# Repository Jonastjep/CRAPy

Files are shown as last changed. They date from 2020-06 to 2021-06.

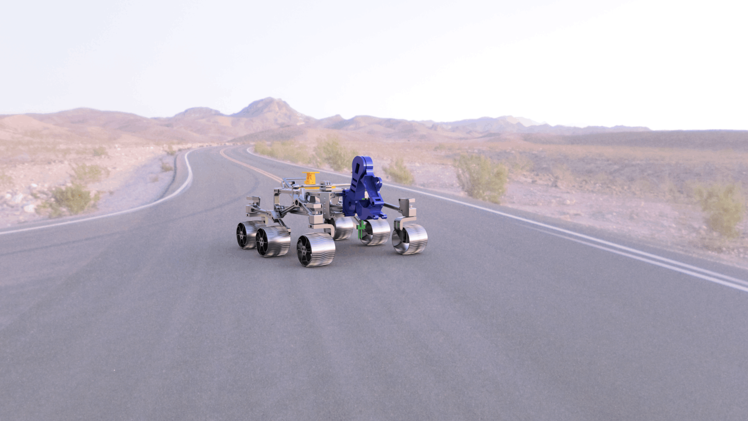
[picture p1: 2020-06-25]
docs/assets/images/for-rendering-final-rover-assembly-2020-jun-22-03-43-39pm-000-customizedview18094494349-png-2000x1126.png

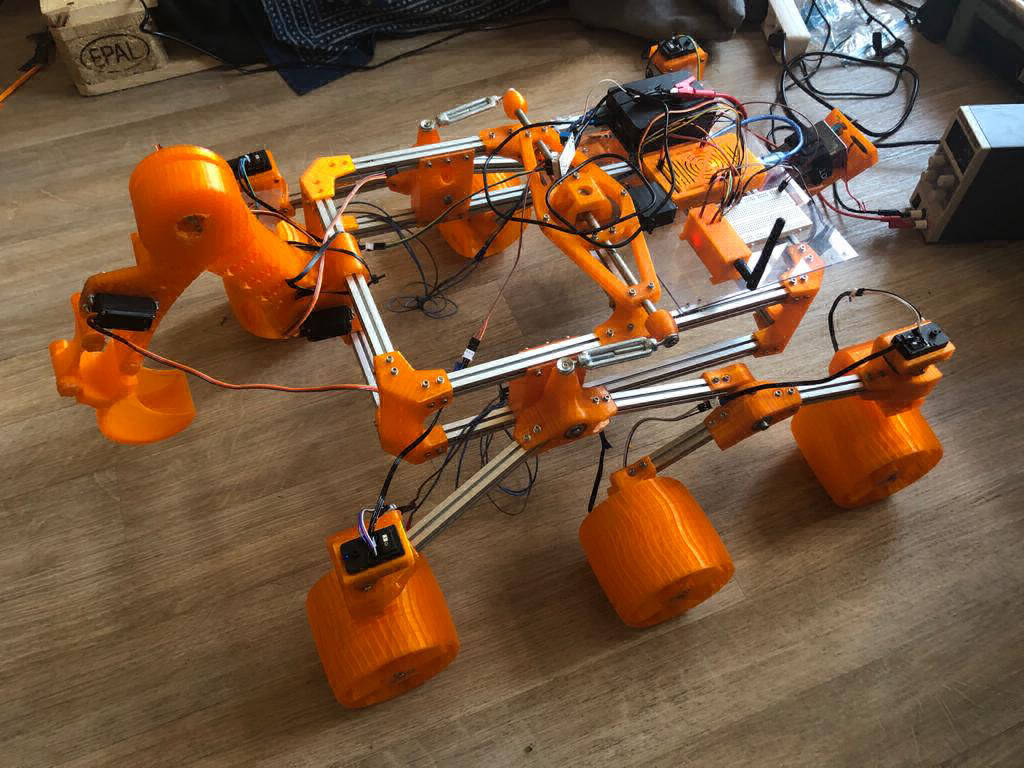
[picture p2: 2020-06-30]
docs/assets/images/whatsapp-image-2020-06-28-at-19.33.52-1024x768.jpg

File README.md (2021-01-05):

# CRAPy Project

The **Controlable Rover Automation Project (CRAPy)** is project is built on the Swappy rover and tries to add new functionalities to it.

# Project Daily Progress Report

## Table of Content

[**Daily Report - 04/01/2021 : Monday 04 January, 2021**](https://github.com/Jonastjep/CRAPy/blob/master/ProgressReport_CRAPy.md#progress-monday-04-january-2021)

[**Daily Report - 05/01/2021 : Tuesday 05 January, 2021**](https://github.com/Jonastjep/CRAPy/blob/master/ProgressReport_CRAPy.md#progress-tuesday-05-january-2021)

[**Daily Report - 06/01/2021 : Wednesday 06 January, 2021**](https://github.com/Jonastjep/CRAPy/blob/master/ProgressReport_CRAPy.md#progress-wednesday-06-january-2021)

[**Daily Report - 07/01/2021 : Thursday 07 January, 2021**](https://github.com/Jonastjep/CRAPy/blob/master/ProgressReport_CRAPy.md#progress-thursday-07-january-2021)

[**Daily Report - 08/01/2021 : Friday 08 January, 2021**](https://github.com/Jonastjep/CRAPy/blob/master/ProgressReport_CRAPy.md#progress-friday-08-january-2021)

[**Daily Report - 09/01/2021 : Saturday 09 January, 2021**](https://github.com/Jonastjep/CRAPy/blob/master/ProgressReport_CRAPy.md#progress-saturday-09-january-2021)

[**Daily Report - 10/01/2021 : Sunday 10 January, 2021**](https://github.com/Jonastjep/CRAPy/blob/master/ProgressReport_CRAPy.md#progress-sunday-10-january-2021)

[**Daily Report - 11/01/2021 : Monday 11 January, 2021**](https://github.com/Jonastjep/CRAPy/blob/master/ProgressReport_CRAPy.md#progress-monday-11-january-2021)

[**Daily Report - 12/01/2021 : Tuesday 12 January, 2021**](https://github.com/Jonastjep/CRAPy/blob/master/ProgressReport_CRAPy.md#progress-tuesday-12-january-2021)

[**Daily Report - 13/01/2021 : Wednesday 13 January, 2021**](https://github.com/Jonastjep/CRAPy/blob/master/ProgressReport_CRAPy.md#progress-wednesday-13-january-2021)

[**Daily Report - 14/01/2021 : Thursday 14 January, 2021**](https://github.com/Jonastjep/CRAPy/blob/master/ProgressReport_CRAPy.md#progress-thursday-14-january-2021)

[**Daily Report - 15/01/2021 : Friday 15 January, 2021**](https://github.com/Jonastjep/CRAPy/blob/master/ProgressReport_CRAPy.md#progress-friday-15-january-2021)

[**Daily Report - 16/01/2021 : Saturday 16 January, 2021**](https://github.com/Jonastjep/CRAPy/blob/master/ProgressReport_CRAPy.md#progress-saturday-16-january-2021)

[**Daily Report - 17/01/2021 : Sunday 17 January, 2021**](https://github.com/Jonastjep/CRAPy/blob/master/ProgressReport_CRAPy.md#progress-sunday-17-january-2021)

[**Daily Report - 18/01/2021 : Monday 18 January, 2021**](https://github.com/Jonastjep/CRAPy/blob/master/ProgressReport_CRAPy.md#progress-monday-18-january-2021)

[**Daily Report - 19/01/2021 : Tuesday 19 January, 2021**](https://github.com/Jonastjep/CRAPy/blob/master/ProgressReport_CRAPy.md#progress-tuesday-19-january-2021)

[**Daily Report - 20/01/2021 : Wednesday 20 January, 2021**](https://github.com/Jonastjep/CRAPy/blob/master/ProgressReport_CRAPy.md#progress-wednesday-20-january-2021)

[**Daily Report - 21/01/2021 : Thursday 21 January, 2021**](https://github.com/Jonastjep/CRAPy/blob/master/ProgressReport_CRAPy.md#progress-thursday-21-january-2021)

[**Daily Report - 22/01/2021 : Friday 22 January, 2021**](https://github.com/Jonastjep/CRAPy/blob/master/ProgressReport_CRAPy.md#progress-friday-22-january-2021)

[**Daily Report - 23/01/2021 : Saturday 23 January, 2021**](https://github.com/Jonastjep/CRAPy/blob/master/ProgressReport_CRAPy.md#progress-saturday-23-january-2021)

[**Daily Report - 24/01/2021 : Sunday 24 January, 2021**](https://github.com/Jonastjep/CRAPy/blob/master/ProgressReport_CRAPy.md#progress-sunday-24-january-2021)

[**Daily Report - 25/01/2021 : Monday 25 January, 2021**](https://github.com/Jonastjep/CRAPy/blob/master/ProgressReport_CRAPy.md#progress-monday-25-january-2021)

[**Daily Report - 26/01/2021 : Tuesday 26 January, 2021**](https://github.com/Jonastjep/CRAPy/blob/master/ProgressReport_CRAPy.md#progress-tuesday-26-january-2021)

[**Daily Report - 27/01/2021 : Wednesday 27 January, 2021**](https://github.com/Jonastjep/CRAPy/blob/master/ProgressReport_CRAPy.md#progress-wednesday-27-january-2021)

[**Daily Report - 28/01/2021 : Thursday 28 January, 2021**](https://github.com/Jonastjep/CRAPy/blob/master/ProgressReport_CRAPy.md#progress-thursday-28-january-2021)

[**Daily Report - 29/01/2021 : Friday 29 January, 2021**](https://github.com/Jonastjep/CRAPy/blob/master/ProgressReport_CRAPy.md#progress-friday-29-january-2021)

[**Daily Report - 30/01/2021 : Saturday 30 January, 2021**](https://github.com/Jonastjep/CRAPy/blob/master/ProgressReport_CRAPy.md#progress-saturday-30-january-2021)

[**Daily Report - 31/01/2021 : Sunday 31 January, 2021**](https://github.com/Jonastjep/CRAPy/blob/master/ProgressReport_CRAPy.md#progress-sunday-31-january-2021)

[**Daily Report - 01/02/2021 : Monday 01 February, 2021**](https://github.com/Jonastjep/CRAPy/blob/master/ProgressReport_CRAPy.md#progress-monday-01-february-2021)

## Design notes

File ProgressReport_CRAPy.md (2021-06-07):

# Progress report of the CRAPy project

## Progress: Monday 04 January, 2021

#### Adjaye:

- Downloaded Fusion 360 and began brainstorming ideas for CAD design.

#### Francesco:
- Carried out first tutorials for processing so I can get some knowledge on the graphical part of the Genetic NN code
- Dowloaded Anaconda, Processing and Atom to work with python
- Read part of the script for creating the plaentary climate model. I have figured out the variables needed but my knowledge of python and physics isn't good enough yet to make sense of most part of the code. If you want to check it out you can find it on (https://github.com/Planet-Factory/claude/blob/master/CLAuDE%20NOM.pdf)

#### Jonas:
- Restructured the github repo for the new project (deleted unecessary files and changed directory struct) and created a [script](https://github.com/Jonastjep/CRAPy/blob/master/Tutorials/createProjStruc.py) to make this file. Also created a table of content for facilitating navigation for the readers.
- Improved the [Genetic NN code](https://github.com/Jonastjep/TinyProjects/tree/main/ObstacleAvoidance/ObstacleAvoidance_js/AI_version "Some cool stuff!") for automated obstacle avoidance ([click here to see the training in action](https://jonastjep.github.io/TinyProjects/)):
	- Changed the NN creation and setup code from homebuilt to TensorFlow.js (more ressource hungry but more efficient on many levels)
	- Tried to improve the fitness function a little (failure to notice any differences, need to rethink the architecture and verify any mistakes)
	- Added a slider change the speed of evolution of the algorithm. Allows for faster training as until now was difficult to see improvement because the training was so slow. We can now focus on the architecture of AI, optimizing the fitness function and seeing how efficient the mutation is (maybe switch from fully random to a Gaussian change). Also until now cross-over has not been implemented, so this should be a big priority.
- Debugged the [user game version](https://github.com/Jonastjep/TinyProjects/tree/main/ObstacleAvoidance/ObstacleAvoidance_js/Game_version) of the AI framework and changed the color palette.
- Looked a little around to see the capabilities of the thermal IR sensor and bicubic interpolation of 2D grid.

#### Juliette:
- Downloaded programs (Fusion 360, installed Python and Atom)
- Read through python textbook, created list of basic commands

#### Marco:
- started to create the environment in which the lidar software can be tested
- learnt how different pathfinding algorithms work in respect to lidar
	- looked over existing code to get an initial idea of how the software can be structured

#### Timon:
- Brainstorm ideas for arm redesign (different platform position, gearing and toolchanger)

#### Sushant:

## Progress: Tuesday 05 January, 2021

#### Adjaye:

- Listened in to the tutorial by Jonas and began testing/practicing making objects in Fusion 360.

#### Francesco:
- Learned the basic use of Arduino and RaspberryPi and how these can be connected to various sensors through flask. The level was very basic but I understood how the basic electronics and programming principles behind switching on and off a LED light connected to an Arduino through a potentiometer. Pretty useful tutorial to get a hang of how arduino's work in case you don't know it yet (https://www.youtube.com/watch?v=nL34zDTPkcs&ab_channel=Afrotechmods)
- Watched another series of tutorials on how to use Processing and how to programme interactive geometrical shapes and drawings
- Attended the amazing tutorial by jonas on how to work with Flask and GitHub
- Dowloaded Git and watched a couple of extra tutorials on how to use Git and the basic principles of Flask

#### Jonas:
- Gave a (very) long and hopefully interesting tutorial about the pleasures of SSH, VNC, Flask and Git/Github.
- Discussed with Sushant the ways he could implement a sensor graphic onto the Flask server and the advantages of JSON or SQLite. Not yet conclusive, so keep an eye on Sushants work.
- Struggled with the AMG8833 thermal sensing module. Got values out, so this is nice, but absolutely impossible to find a way to plot it and refused to use PyGame, which would have no feasible way of implementing to a flask app. Tried matplotlib, seaborn, plotly and openCV, best result to have come out was OpenCV but was not successful at animating it. Just realized that p5.js might be a good possibility, but have to see how to pass the data to the script... Positive side is that the sensor is working and it is possible to see from the values the wiggle of fingers.
	- The problems encountered is how do I create the 8x8 images, and simultaneously send them to the js script for reading
	- **Late night update, possibility using websocket. To be investigated further...**
- Also Started working on a cheat file for the Git/ssh commands. Will be available tomorrow probably

#### Juliette:
- Attended Jonas' tutorials on Git/GitHub, SSH, and Flask and began practicing/researching basic concepts.
- Downloaded and Installed Git and Flask
- Started practicing and brainstorming on Fusion 360 

#### Marco:
- succesfully created version one of the environment to test the lidar. Point clouds are now generated on command if objects are within range of the simulated lidar. Still need to fix so the lidar range is blocked by objects (currently there is clipping).
	- The simulated rover only moves up/down/left/right instead of forward/backwards/rotation -> this needs to be fixed to better simulate the rovers movements
	- the lidar also will need to be changed to simulate blockages

#### Timon:
- Optimize slicer profile for PETG filament and do test prints
- Develop more concrete ideas for the robotic arm and find out what the different available motors are capable of.

#### Sushant:

## Progress: Wednesday 06 January, 2021

#### Adjaye:

- Collaborating with Timon to decide which aspects of the design we will be in charge of and getting the basic run down of the parts needed in this iteration of the project and their importance from Marco and Jonas.

#### Francesco:
- Manged to set my git (baby steps for a bio students)
- Looking into using python to code  for the sensors' module. Still far away from what I need to know

#### Jonas:
- Wrote the Git/Github [tutorial](https://github.com/Jonastjep/CRAPy/blob/master/Tutorials/Setting_Git%26Github.md) for the team
- Managed to stream the thermal camera using Python websockets and processing!! :) This should be very low computing for the RPi and low latency as it's the host computer that does all the work. Nice video example. Still need to do the interpolation (we hope for bicubic) that might make it a bit heavier for the Rpi but not much. But this took some time...
- Had a look at the LiDAR and despaired on the discovery that it can only be controlled through ROS

#### Juliette:
- Began Flask tutorial from the official website
- Created first app with Flask that displays "Hello, world" when using the link of the ip adress.

#### Marco:
- Fixed lidar environment.
	- now only objects in rover fov are added to point cloud - as would be the case with real lidar. movement mechanic logic was changed to make smoother use. rover no longer clips through obstacles. point clouds still generated on command. personal computer broke so started using jonas' spare. files in branch Marco are by marco despite being pushed by different user - this valid until specified. 
- 3d design
	- discussed with adjaye and timon the way forward regarding design of components. outlined 6 reccesary practical aspects of the project; 5x ultrasound mounts for hardpoints onto rover body, robotic arm with manipluation attachment, solar panel/ material deposit tray, fix current defective pieces, camera/lidar mount, other small sensor housings.
	- work split as follows; timon - robotic arm, adjaye - solar panel and material deposit, marco - camera and lidar mount, whole team - fix current defective pieces,  ultrasound mounts and small sensor housings are trivial designs open to whoever wants.

#### Timon:
-3D model bracket that mounts to rover for arm
- discoss with adjaye how the arm and the solar panel can be operated on the rover
- start tallking about ideas of how to stop the axles from slipping

#### Sushant:

## Progress: Thursday 07 January, 2021

#### Adjaye: 
- Continuing to develop ideas for the rover's solar panel and sample box design.

#### Francesco:
- Menaged to connect to raspberry pi from Italy through ssh and VNC, controlled the temperature sensor.
- Next step is try to build a database with sqlite, store in it the data obtained from the temperature sensor and form a graph using Matplotlib. Then display the data using JustGage and then make the graphed data available through a web app made with flask. It's a work in progress
- To do all pf this with my little knowledge I have also been following some tutorials on how to programme with python, especially in the context of 

#### Jonas:
- Discovered the pressure sensor was not working (only after a loooong period of troubleshooting) so had to solder a new one together and conect it to the RPi to allow access through ssh for Francesco. Also had to figure out how to configure the I2P port address for the [Adafruit BMP280 libraries](https://github.com/adafruit/Adafruit_CircuitPython_BMP280/blob/f65303074498e07db883e73c067a8b9e491451a2/adafruit_bmp280.py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). Alot of issues due to the fact our sensor is not genuine. Also had to figure out if it was a BME280 or BMP280 (it's the latter). Alot of time went into just figuring out these things.
- Had a zoom conference with Italy to help with taking control of a remote server (a RPi) and using it to run some python software.
- Spent some time reflashing another RPi and updating it up. Issues with the headless connection through wifi but fixable.

#### Juliette:
- Continued tutorial for a longer app with Flask
- Trip back to Maastricht, delays in both flight and trains.

#### Marco:
- partially installed the neccesary ROS software needed to operate lidar (still proving to be tricky)
- began designing first iteration of the camera/lidar sensor mast
- reviewed current physical design flaws and neccesary improvements 
- reveiwed methods to export point cloud data from ROS into a more managable format for end-used consumption
- set up fusion 360 team and made accessible the previous design of the rover for design reference

#### Timon:
- Develop and 3D print (and improve it again) a snap on attachmet that can be used to attach all other sensors etc. to the rover.
- identify broken parts on the rover that need to be reprinted
- start printing replacement parts with reiforcememnt out of PETG for the rover
- experiment with drilling of the axles to aviod slipping
- retrieving a vice to hold the axles while drilling them
- drilling hoes into all axles to prevent slipping

#### Sushant:

## Progress: Friday 08 January, 2021

#### Adjaye:
- Collaborating with Timon on solar panel and sample box design
- Begin implementing the design into CAD

#### Francesco:
- Still working on the creation of a web app to store and display the data from the temperature and pressure sensor (BMP280). Until now I managed to build a database with sqlite, store in it the data obtained from the temperature sensor. The next step is to form a graph using Matplotlib and display the data using JustGage. Ultimately the app for display will be made with flask but to do so I think I will need to be in maastricht to get some assistance from more experienced prigrammers... Jonas has been very helpful!
- Menaged to create a working database and programme to store the data directly from the sensor. Next step is to create a query, to format the raw data into a readable form. Then a falask web app to visualise this form.

#### Jonas:
- Wrote the Raspberry [Pi setup/connection tutorial](https://github.com/Jonastjep/CRAPy/blob/master/Tutorials/Setting_Up_The_RPi.md) that explains how to setup a headless RPi and take control of it. 
- Also wrote the [ssh and remote control of system tutorial](https://github.com/Jonastjep/CRAPy/blob/master/Tutorials/RemoteConnection_tutorial.md), to explain how to remotely use a GNU/Linux system (specifically RPi) from afar.
- Helped Juliette a little bit with flask (Vorführeffekt) and gave some advice to Francesco.
- Disassembled the suspentions of the Rover with Timon to test out the new PETG part, but infill was too low and piece cracked when pushing it with a bearing. 
- Rethought the fitness function of the genetic AI: add negative fitness points to models that turn too much and that don't push on the forward button. This should take care of the ones that turn in a circle indefinitely as well as the ones that just stop down.
	- Added features that allow for death timer to be removed and added the choice to leave the forward motion to the rover (we can now force the rover to always have it's foot on the accelerator - it totally removes the problem of static cars and disfavours the rotating ones)

#### Juliette:
- Had issues with the Flask app and the virtual environment, solved now.
- Installed PUTTy for SSH and connected to Raspberry pi
- Making app with flask and SQLite for sensors from Raspberrypi

#### Marco:
- continued the design process for the sensor mast, worked through two iterations each using a different design to move camera and optical equiptment. finalised the orientation of equiptment on the mast, as lidar needs a 360 degree unimpeded view whereas if camera and optical equiptment has small blindspots it is not a big issue (given that default position is unimpeded).

#### Timon:
- Develop and test new slicing profile for increased strength PETG parts
- Start printing PETG replacement parts

#### Sushant:

## Progress: Saturday 09 January, 2021

#### Adjaye: 
- Implemented the first version of the sample collection box into Fusion 360 that utilizes a slider crank to open and close the box.

#### Francesco:
No progress due to trip from Italy to Maastrict! The car broke down.

#### Jonas:
- Worked on implementing the new fitness model to the genetic algorithm. The changes don't gives very different results, probably because the values are not well set... Need to sit down and think about the optimal aditions of fitness values to the score.
- Also looked into making the cross-over. I (or someone else from the team) should probably continue the python implementation, as python has many more tools for these tasks. It's just nice that p5.js can be run on the browser.

#### Juliette:
- Database creation using sqlite. Used commands in shell to create a table, insert data, and retrieve the table to ensure proper functioning of code.
- Learn to structure python scripts for database creation as well so commands don't need to be manually entered every time but instead it is better to just call in the python file with the commands included in it.

#### Marco:
- completed the design for the uper part sensor mast where optical sensors are located. now only need to design a secure method to fix bottom end of pvc pipe to rover body and sensor assembly will be complete. **visible in my branch if yous are curious**

#### Timon:
- Continued printing replacement parts

#### Sushant:

## Progress: Sunday 10 January, 2021

#### Adjaye: 

- Day off

#### Francesco:
- Arrived in Maastricht late due to journey delay (broken car)
- Menaged to set up another programme to log data automatically and have been working on a way to let the programme run continously but let it stop at a precise point, like once every single hour it should collect informations, feed them to the database and then stop, to start again in the next hour. Still need to define well how to do it.

#### Jonas:
- total day off :) (almost)

#### Juliette:
- Researched possible sensors that we would be using (still need to know what sensors we have to research how they work)
- Learned about DHT sensors and followed basic tutorials on it

#### Marco:
- nothing this was day off 

#### Timon:
- Continued printing replacement parts 
- Enjoyed the weekend

#### Sushant:

## Progress: Monday 11 January, 2021

#### Adjaye:
- Continuing to work on the sample box v1.

#### Francesco:
- I have been working on the second part in the creation of a web app, trying to form a quary. However, I have been stuck all day on the same problem, the storing table does not get recognised by the gueryTableBMP280.py programme and I can't figure out why!
- Just menaged to make the query work, it was due to a spelling mistake!!!

#### Jonas:
- Printed more wheel parts in PLA and tested using PrusaSlicer instead of Cura: excellent results, I'm converted!
- Reassembled the rover almost fully, the shafts are still a pain to install, but PETG seems promising. Some older parts look on the verge of collapse, but planning on tying to add some epoxy for structural integrity.
- Helped a little bit around with Flask and the ROS installation, when needed.

#### Juliette:
- Went over the GPS files in the github to understand what has been done and how (defining line by line how the python files are written, which also helps to learn python structure, the different functions, and what it is possible to do)
- Attempted to work with pressure/temp sensor to create database using sqlite (not quite successful yet)

#### Marco:
- succesfully downloaded and istalled the neccesary ROS onto a secondary raspberryPi to test if it worked. Did not. had to wipe the microSD and reinstall the software with little success. Now trying to retrace steps and redo all with extra attention to see if steps were overlooked. If the ROS and other software neccesary to run lidar on a raspberryPi can be succesfully downloaded in the following days then there should be no probelem implementing on actual rover. 

#### Timon:
- Made the bracket that attaches the arm to the chassis in fusion 360
- made the motor mount for rotation of the arm in F360
- Transferred bearings from old to new parts and hammered them in
- Assembled suspension and drivetrain related parts of the rover

#### Sushant:

## Progress: Tuesday 12 January, 2021

#### Adjaye: 

- Gathered inspiration for solar panel design
- Prepared for exam on thursday in the evening

#### Francesco:

#### Jonas:
- Started the prints for the camera and LiDAR attachement module, will probably have the module tomorrow
- Managed to finally make the LiDAR work with Marco, what a pleasure to see the point cloud delimiting my room! I just helped debugging a little the commands needed for the setting up
- Discussed sensor modules with Francesco and Juliette. Starting to figure out where we want to go, probably starting on the datacollection tomorrow or something. We'll see how well the nRF24 sensors work and how we can implement all this.
- Managed to create a mapping inteface for GPS data. Works super nicely, just waiting to have implemented many more features than simply all data or query a certain amount of latest data (for example, give two dates, and map the travel between; also centralize the map on the tracks first point, still to do). Will probably make pull request tomorrow. Had issues with cached json files in browser, but found solution.
- Wrote some demos for data conversion between CSV, SQLite database and JSON. Good for the people of the group interested.
-Also this mapping is proof of concept of how we will make all of the interactive plots etc on the webapp: This worked fabulously and leaves us with alot of control. Need to discuss this with the others tomorrow.

#### Juliette:
- Discussed sensors with Jonas and Francesco to figure out a plan (how to implement them together)
- Attempted with Francesco to establish communication between Arduino and Raspberry pi through rnf24l01 transceivers (searched for standard connection mappings between sensors and raspberry pi) - Had issues making this work.
- Found a tutorial for nrf24l01 communication from Arduino to Arduino (instead of Arduino to Raspberrypi) https://lastminuteengineers.com/nrf24l01-arduino-wireless-communication/ (will run this on wednesday with Francesco)

#### Marco:
- lidar now working (mainly thanks to jonas for troubleshooting with me). required several reflashing of sd card until we chose to use a disk image with ROS kinetic alreadz installed with ubuntu 16. this allowed us to bypass several installation steps that were previously problematic. running codes to activate and perate lidar are as follows. `roslaunch ydlidar_ros_driver X4.launch` hen in another windown run `rviz` to open the ROS software. then within the ROS software `file>open confi>ubuntu>ydlidar_ws>src>ydlidar_ros_driver/launch/lidar.rviz` to get real time lidar info on screen. 
	- looks cool and proves it works, does not yet actually create a map to then be stored. The next steps are as follows; implement SLAM to create a static point cloud that can then be exported to flask web app.this will alow the end user to view the map created by the rover in real time (hopefully). 
	- should it all work then the actual rasPi used on the rover will need to be reflashed with disk image used on test rasPi. everything will need to be redone on the actual rasPi, for this first i will make a tutorial/log of everything we did to get the current rasPi working, not only to make replication easier but also to ensure future groups are able to use the LiDAR module if they want to.

#### Timon:
- Discussed with Adjaye various ways of how the solar panel could be lifted (worm gear, regular gear reduction, linear actuator)
- discussed more concretely what areas of the front of the rover are available for which mechanisms
- Designed the base of the arm which holds the first link 
- Started with the first link of the arm.

#### Sushant:

## Progress: Wednesday 13 January, 2021

#### Adjaye: 

- Took the day off as the exam was the next day.

#### Francesco:
- Have been working on the connection between raspberry pi and arduino using the radio frequencies. Following this tutorial https://medium.com/@anujdev11/communication-between-arduino-and-raspberry-pi-using-nrf24l01-818687f7f363
- The tutorial we were following didn't prove useful so we changed plan, with Juliette we will try to connect two arduinos, one attached to the rover's raspberry pi and one attached to the headquarters' raspberry pi.
- With jonas and juliette we menaged to make two NRF24L01 communicate, one reciver and one transmitter, but we fail to have a clear connection where we have a message being recieved aaandaa a message being sent back, to confirm the message being recieved.

#### Jonas:

#### Juliette:
- Worked with Francesco on nrf24l01 communication. Attempted again to follow a tutorial between Raspberry pi and Arduino (see Francesco's report for link) but it was unsuccesful. Decided to stick with Arduino to Arduino wireless communication.
- With the help of Jonas, Francesco and I finally made the two nrf24l01 communicate, following a simple code for two-way transmission (one code for the transmitter and one for the receiver) https://forum.arduino.cc/index.php?topic=421081
- Problems receiving an acknowledgement message back from the receiver so transmitter cannot confirm message has been successfully received.

#### Marco:
- wrote tutorial on how to set-up rasPi for lidar operation, starting from a new blank rasPi all the way to lidar operation. Visible under tutorials folder of master branch and titled Lidar_rPi_tutorial.md
- worked on initial  3d printed parts of the sensor mast design to prepare them for assembly.

#### Timon:
- Improved the base of the arm and other parts so that the first link can rotate down as far as possible. This is so that the arm can be as short as possible to make it more lighweight and easier to lift for the motors
- indentified broken hub parts that need to be replaced
- retrieved heat inserts and screws from broken parts
- searched together all screws neccesary for the wheel assembly
- put heat inserts and screws into new parts
- Partially assembled hubs and motors

#### Sushant:

## Progress: Thursday 14 January, 2021

#### Adjaye:

- Day of exam, continued to work on design in the evening.

#### Francesco:
- Found this tutorial https://forum.arduino.cc/index.php?topic=623796.0 to conenct arduinos and send data. We are going to test the code and connection between our two NRF24L01 modules 
- With Juliette we menaged to make two antennas nRF24L01 communicate at long distance, sending messages and receving them. The confirmation of having recieved the message doesn't work from reciver to transmitter. Next step is to make that work, so that we can have the rover confirming a message has been recieved or sent. N.B. This was difficult (jonas agrees)
- We menaged to get the reciver to send a confirmation signal to the transmitter. The problem wasn't the code but rather the connection and the equipment we were using, probaby in relation to the cables and the way in which they connect

#### Jonas:

#### Juliette:
- Working with Francesco, still trying to make the nrf24l01 sensors work.
- Researching how to send data from sensors through transceivers.
- nrf24l01 worked!! at "long" distance! Acknowledgement message still missing, need to review code and find where it fails to send confirmation receipt.
- Managed to get 7 confirmation messages from the receiver! Possible problems with connections
- Placed a few screws here and there in the rover

#### Marco:

#### Timon:
- Realize that a few more hubs are broken
- Harvest heat inserts from old hubs and put into new hubs
- Shorten axles that were too long, using a plastic bag in the process
- mount wheel carriers onto the suspension assembly
- attach all 10 motors, by numbers to each position
- shorten screws because there weren´t enough of the right size
- attach wheels
FINALLY 10 WHEELS THAT DON´T SLIP!!! 

#### Sushant:

## Progress: Friday 15 January, 2021

#### Adjaye:

#### Francesco:
- With Juliette we have been trying to send the data directly from the arduino to the other through he nRF24L01 module underthe form of strings. This tutorial might be useful https://forum.arduino.cc/index.php?topic=436525.0. We should also start to think about the way to send a serial communication from the sensors to the raspberry pi and form a database there. But this is for future moment.
- We gave up on sending data between the two nRF24L01 modules because the connection is too unstable and continously brakes, which also makes it very difficult to test the code and the way in which data are sent. NOTE on future improvements: use more powerful antennas and to try to have a more stable connection

#### Jonas:

#### Juliette:
- Spent first hours working with each sensor (separately) to obtain individual codes as well as proper cable connections for each (that way we can be sure we can make them all work properly. Did this for mq2-gas sensor | hcsro4-ultra sound sensor | dht11 - temperature and humidity sensor)
- Worked on combining code of nrf24l01 transmitter sensor with one of the individual scripts (chose hcsro4 - ultra sound sensor for this because it was the one working best)
- Assembled the arduino connection with the two sensos (nrf24l01-transmitter and hcsro4)
- Ran into problems compiling the script due to type mismatch between the needed type for the transmitter (String) and the one established in the sensor (long)
- Worked with Francesco finding tutorials to send sensor data from one Arduino to the other as Strings
- With the help of jonas we used .concate() to adhere the data into a string, this solved the compiling problem
- Uploaded the script and attempted to send sensor data over the transceivers. The receiver did not get any message at all. Printed values in the code to make sure the data variable was indeed containing the data received from the ultra sound sensor, this was correct. 
- Attempted to run simple code again (which had work the day before and had even sent acknowledgement receipts). This connection failed as well. Thus, the problem was deemed to be within the connection of the trasnceivers. Gave up on sending data between the nrf24l01 modules.
- Focused on producing a combined code by adding one more sensor (the mq2- gas sensor)
- Managed to compile a code containing all the info for the nrf24l01 transmitter, the hcsro4 ultra sound sensor, and the mq2 gas sensor.
- Made all connection to the arduino, uploaded the script, ran it. Successful retrieval of data.

#### Marco:

#### Timon:
- experiment with rubber bands to determine what extensions they should operate at and what force they are able to provide
- Designed first link of the robotic arm

#### Sushant:

## Progress: Saturday 16 January, 2021

#### Adjaye:

#### Francesco:
- Have been working on two main things, the first one is to find a way to transform the data from the arduino into a json format to be sent over to the raspberry pi. The other is the creation of a programme to recive the data on the raspberry pi and serial it into different variables to store in arrays which will then be used to form sqlite database. I have menaged to get a bit further on this part, mainly due to the fact that today I didn't have any access to the arduino, so it was difficult to test the code.
- I still have to understand better how to sort out the data for the serial communication, but once that is done, the next step is create a flask app and display all the data collected into the sqlite database.
#### Jonas:

#### Juliette:
- Looked into JSON structure in arduino to send organized data from the code of the arduino to the Raspberry pi
- Cleaned up a bit the combined code of the arduino

#### Marco:

#### Timon:
- starting with printing of parts of the robotic arm

#### Sushant:

## Progress: Sunday 17 January, 2021

#### Adjaye:

#### Francesco:
- Scratched off part of yesterday's work because json is needed after the data has been stored in sqlite, not before. Menaged to write a code that takes the data from serial of arduino, stores them into a sqlite database.
- Through another programme I convert the sqlite data into the json type data, which will be then used in the flask app that I am currently writing.
- All these programs still need to be tested, but the main part of that will be simply trubleshooting
- We will also need to start to write a programme for the arm and the light sensors.

#### Jonas:

#### Juliette:
- Added dht11 sensor to the combined code in the arduino. (Now this code has nrf24l01, hcsro4, mq2, and dht11 implemented - Compiled successfully).
- Organized data in a variable that separates values with a ",". Need to figure out how to implement json structure. (jonas explained, json not needed from Arduino).
- Error when running as the data for dht11 sensor returns 0 and 0 for temperature and humidity.
- Ran sensor individually with script done on friday, it works. Currently trying to find the issue within the combined code as the logic and commands are the same.

#### Marco:

#### Timon:
- continue printing parts of the robotic arm
- testing fitment of pars
- changing parameters of the parts (e.g. bearing fitment) 

#### Sushant:

## Progress: Monday 18 January, 2021

#### Adjaye:

- Presented  slided crank design to Marco, the design had too many issues in that it had too many moving parts, and was not feasible for the space of the rover and its other components. The design for the solar panel had a similar issue and would have gotten in the way of the lidar and camera.

-Beginning of a new design for both collection box and solar panel.

#### Francesco:
- Created the first part of the web app and tested it with a randomly populated set of data. Passed on the whole day trouble shooting, the code is very big.
- Worked with Chart.js and revisioned how to make graphs

#### Jonas:

#### Juliette:
- Found issue with dht11 sensor, fixed code (was missing a read command before retrieving the data). 
- Now working with bmp280 sensor. Having issues running examples and actually, any code ("sensor not detected").
- Problem solved with the help of Jonas: Edited library, used the SPI protocol instead of I2C, and added .begin() command. 
Now implemented individual script into combined code. 
- All 5 sensors (nrf24l01, hcsro4, mq2, dht11, and bmp280) are now in the script :) Everything runs correctly!
- Organized the data (small details such as no spaces, different headers, proper separators)
- Placed the connections in the Arduino Mega taking into account future needed pins (bmp280 changed to I2C since SPI is needed for nrf24l01).
- Need to add GPS sensor now. Running individual script, I get responses but no data. Might be due to our positioning not getting any data from satellites.
- Soldered cables, added some heat inserts, and used a hammer for apparently the first time!?

#### Marco:

#### Timon:
- designing second link of the robotic arm
- printing more parts of the arm
#### Sushant:

## Progress: Tuesday 19 January, 2021

#### Adjaye:

- Continuing to work on design.

#### Francesco:
- Continued with yesterday's trouble shooting and have been working on some ideas for the video

#### Jonas:

#### Juliette:
- Attempted to make GPS work. Errors in connections -> "Check wiring". It doesnt recognize the module in the program.
- Note: Tx and Rx connections are inverted to arduino!!
- Examples not running properly
- Using GPS code from github returns empty data (but at least sensor is running now). Implemented code into combined script.
Terrible weather might be making the connection to satellites difficult.

#### Marco:

#### Timon:
- take all parts and assemble to a working arm! (longer than expected)
- print more hubs that don´t break (more perimeters jonas!)
#### Sushant:

## Progress: Wednesday 20 January, 2021

#### Adjaye:

- Finished design, the new collection box design recieved the go ahead as well as the solar panel raiser.

#### Francesco:
- Adapted the web app code with the Arduino code from Juliette. I have also created two databases to store data from the GPS in one, and data from the sensor in the other.
- Also began to write the script for the video

#### Jonas:

#### Juliette:
- Starting box design for sensors, taking measurements.
- Need to add more ultrasound sensors to code!

#### Marco:

#### Timon:
- Construct part that pitches and rotates the toolhead
- adapt the grabber
- print grabber
- steal jonas´s measurements and make an alternative model of his desing without consent :P
- start printing pieces to hold solar panel

#### Sushant:

## Progress: Thursday 21 January, 2021

#### Adjaye:
- Solar Panel raiser was dropped due to lack of time and so preparing the collection box was put on priority.

#### Francesco:
- Finished the script for the video this morning. I am waiting for a reply from the members of the team.

#### Jonas:

#### Juliette:
- Finished box design. Need to check measurements are proper, design is feasible and efficient. Then need to print.
- Added 4 ultrasound sensors to the code (quite lengthy, might be optimzed).
- Noticed that the sensors dont detect me standing in front but it does detect a box - or my hand - so.

#### Marco:

#### Timon:
- Assemble grabber as far as possible without motors
- break holder for solar panel
- make new design for solar panel holder
- test motors (they move)
- print new solar panel holders
- print knuckles wrong (not mirrored)
- print rotating thingy

#### Sushant:

## Progress: Friday 22 January, 2021

#### Adjaye:

- Cutting plexiglass for the assembling of the collection box.
- Assembled turning axle box.

#### Francesco:
- Worked on a light following system for the rover
- Wrote part of the report's introduction
- Revised the web app code

#### Jonas:

#### Juliette:

#### Marco:

#### Timon:
- adapt code to have 6 servos
- convert code such that settings are done and displayed in degree
- adapt script 
- be happy

#### Sushant:

## Progress: Saturday 23 January, 2021

#### Adjaye:

- Helped with the making of videos
- Sanding/adjusting the collection box
- As it would turn out the collection box may not be most practical so a different one was designed in Fusion 360

#### Francesco:
- Took half of the presentation videos
- Soldered and assembled the light following system
- Wrote part of the report

#### Jonas:

#### Juliette:

#### Marco:

#### Timon:
- adapt script of what I say. 
- get articles for the report
- work ( the thing where you do something and get money)

#### Sushant:

## Progress: Sunday 24 January, 2021

#### Adjaye:

#### Francesco:

#### Jonas:

#### Juliette:

#### Marco:

#### Timon:
- wire up rover (ORganize cables wth zip ties, solder connections, put connections in the rover NICELY!)
- Red-> grabber, Purple-> rotation base (everything else in between follows the colors of the rainbow shorter wavelength -> further down the arm).
- record my parts of the video
- peer review 
- vibe
- collect key points for the report
- 

#### Sushant:

## Progress: Monday 25 January, 2021

#### Adjaye:

#### Francesco:

#### Jonas:

#### Juliette:

#### Marco:

#### Timon:

#### Sushant:

## Progress: Tuesday 26 January, 2021

#### Adjaye:

#### Francesco:

#### Jonas:

#### Juliette:

#### Marco:

#### Timon:

#### Sushant:

## Progress: Wednesday 27 January, 2021

#### Adjaye:

#### Francesco:

#### Jonas:

#### Juliette:

#### Marco:

#### Timon:

#### Sushant:

## Progress: Thursday 28 January, 2021

#### Adjaye:

#### Francesco:

#### Jonas:

#### Juliette:

#### Marco:

#### Timon:

#### Sushant:

## Progress: Friday 29 January, 2021

#### Adjaye:

#### Francesco:

#### Jonas:

#### Juliette:

#### Marco:

#### Timon:

#### Sushant:

## Progress: Saturday 30 January, 2021

#### Adjaye:

#### Francesco:

#### Jonas:

#### Juliette:

#### Marco:

#### Timon:

#### Sushant:

## Progress: Sunday 31 January, 2021

#### Adjaye:

#### Francesco:

#### Jonas:

#### Juliette:

#### Marco:

#### Timon:

#### Sushant:

## Progress: Monday 01 February, 2021

#### Adjaye:

#### Francesco:

#### Jonas:

#### Juliette:

#### Marco:

#### Timon:
fun

#### Sushant:

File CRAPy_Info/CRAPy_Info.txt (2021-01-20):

pwd  	      : BroverInc
user 	      : pi
computer name : broverpi

static ip_address=192.168.4.1
ssid: BroverInk_Network
pwd: BroverInk1234

Sensor Mast:
GPIO:
17 Tilt - Slim servo
27 Pan - Thick servo

Disable access point :

- sudo systemctl disable hostapd dnsmasq
- comment the static ip config in /etc/dhcpcd.conf
- sudo reboot

Enable access point

- sudo systemctl enable hostapd dnsmasq
- comment the static IP config in /etc/dhcpcd.conf
- sudo reboot

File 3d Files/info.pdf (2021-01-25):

Print every file once, except the pillar.stl which needs four (4) copies.

Components in red are pre-existing, grey is what needs to be printed.

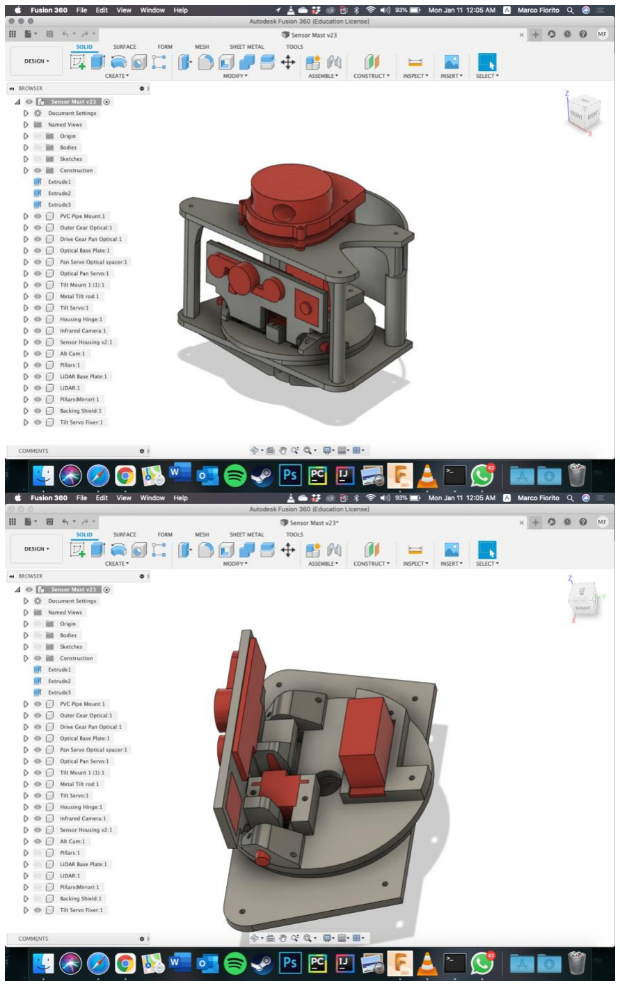
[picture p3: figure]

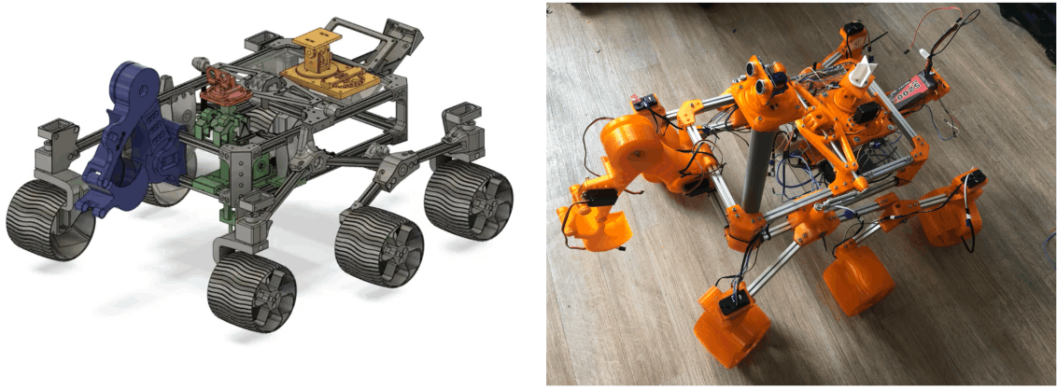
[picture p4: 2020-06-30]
docs/assets/images/screen-shot-2020-06-30-at-12.04.13-pm-1132x418.png

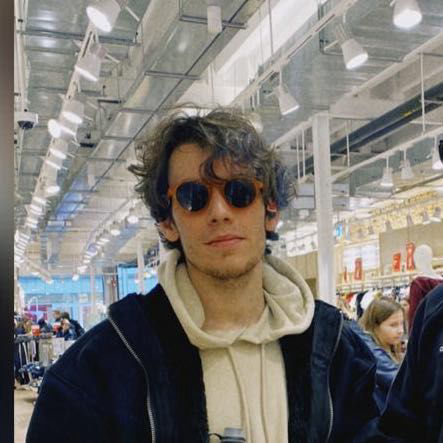
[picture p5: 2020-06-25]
docs/assets/images/69473030-2541841602751203-3235094702887111045-n-443x443.jpg

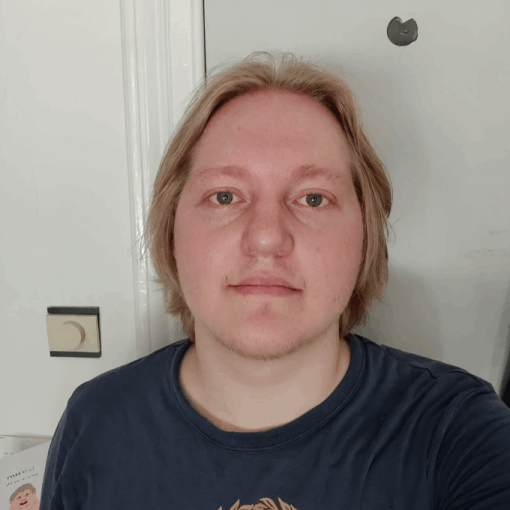
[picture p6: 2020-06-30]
docs/assets/images/screen-shot-2020-06-29-at-1.16.12-pm-510x510.png

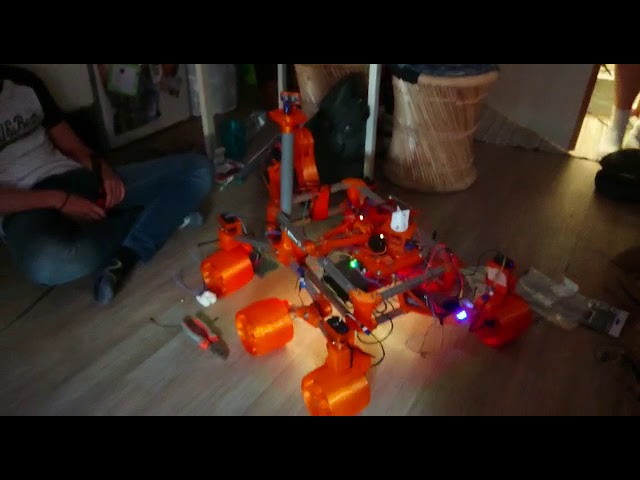
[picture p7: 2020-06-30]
docs/assets/images/mobirise2020529-131212020-5-2-9-54-42.jpg

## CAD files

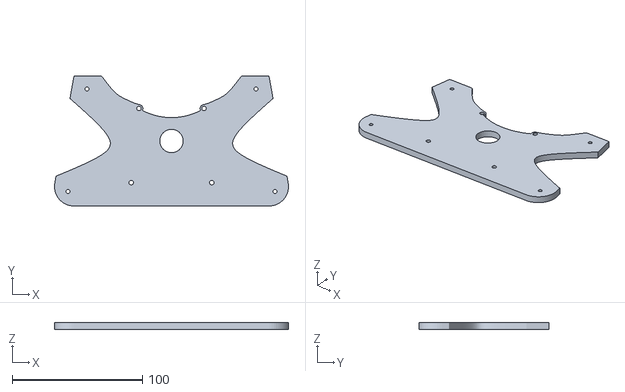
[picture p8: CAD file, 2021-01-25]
3d Files/Sensor Mast v22 indv comp/LiDAR Base Plate.stl
180.0 x 100.0 x 5.00

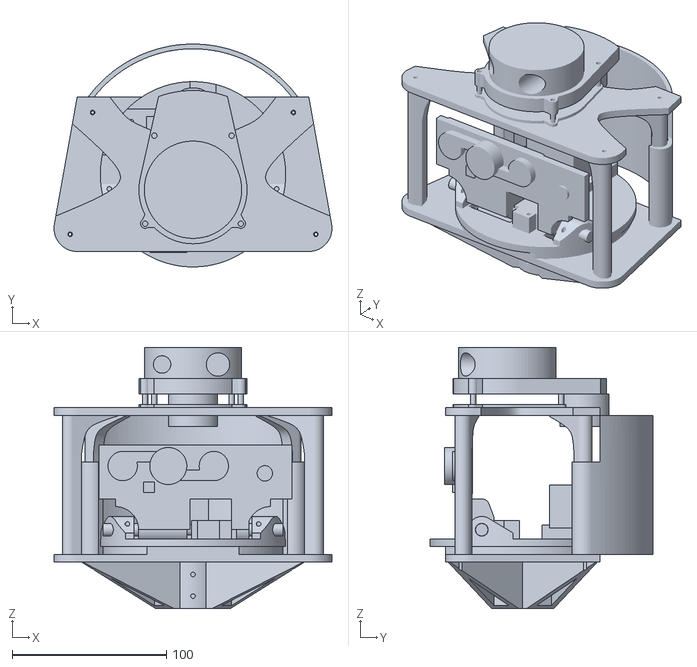
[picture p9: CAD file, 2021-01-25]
3d Files/Sensor Mast v22.stl
180.0 x 144.3 x 169.0

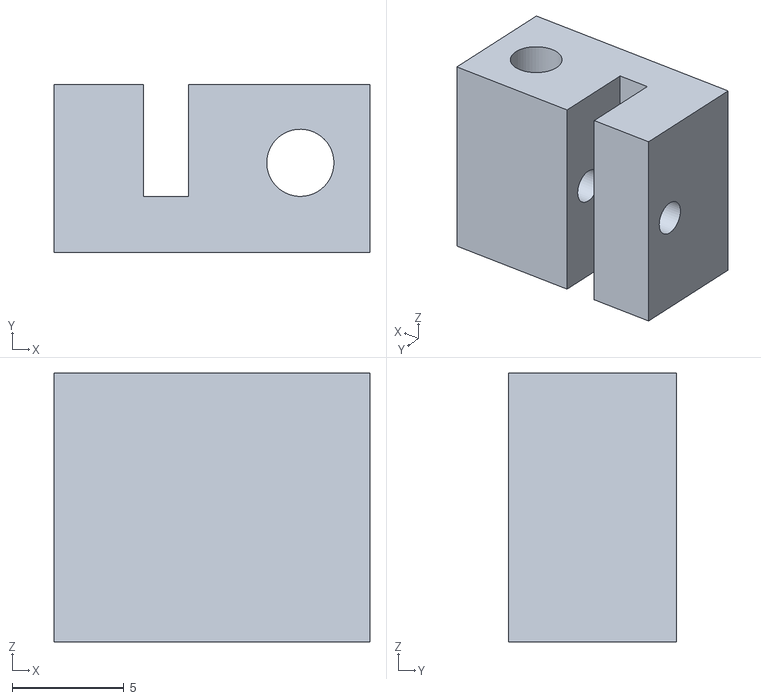
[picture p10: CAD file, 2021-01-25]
3d Files/Sensor Mast v22 indv comp/Tilt Servo FixerBody2.stl
14.1 x 7.49 x 12.0

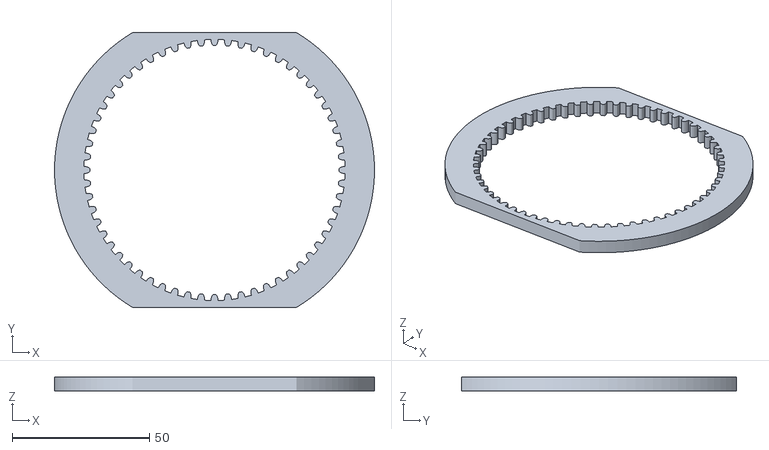
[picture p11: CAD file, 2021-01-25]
3d Files/Sensor Mast v22 indv comp/Outer Gear Optical.stl
116.4 x 100.0 x 5.00

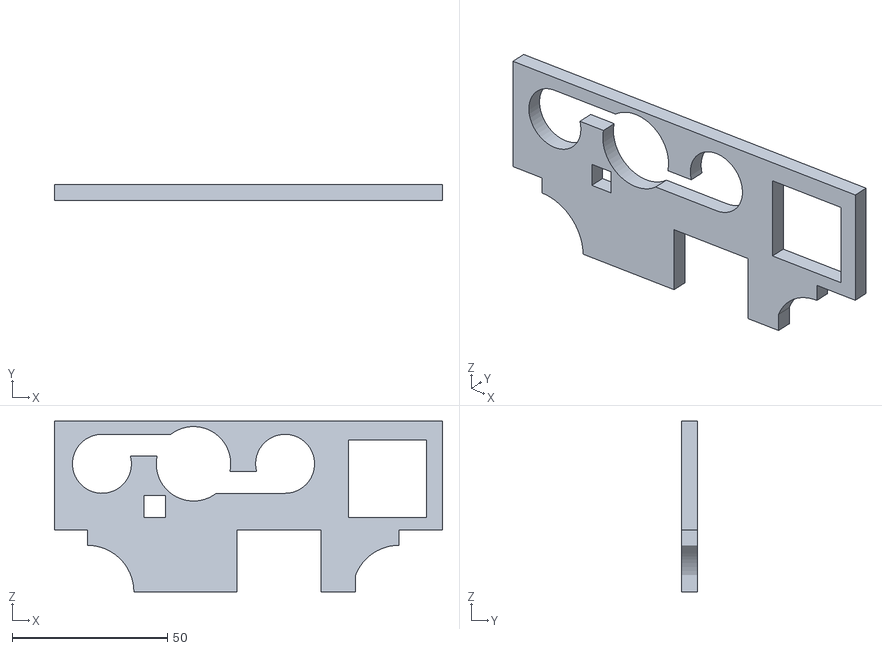
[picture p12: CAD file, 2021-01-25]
3d Files/Sensor Mast v22 indv comp/Sensor Housing.stl
125.0 x 5.00 x 55.0

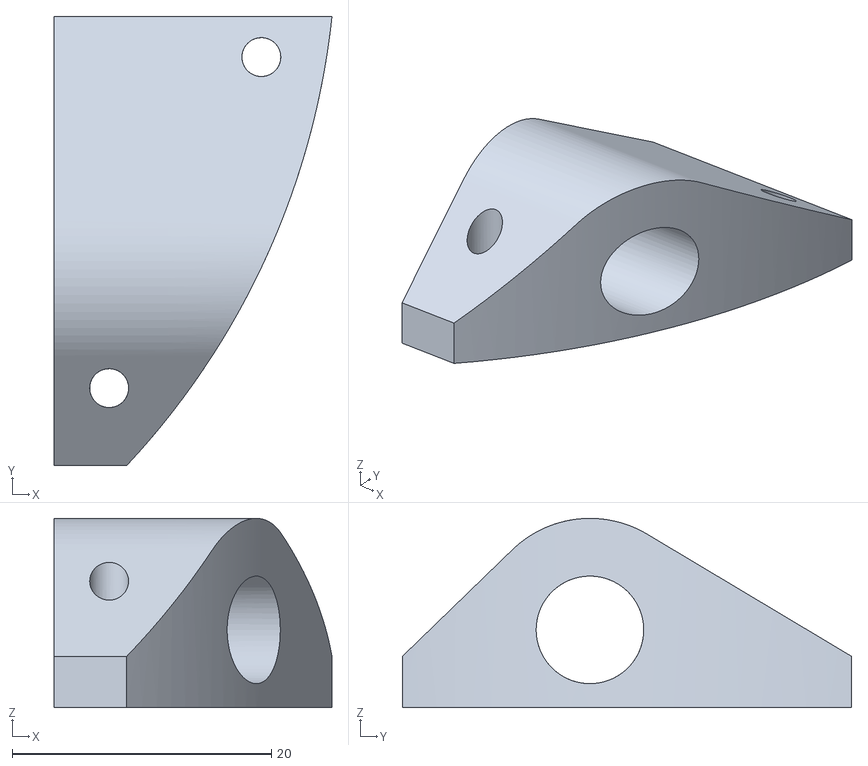
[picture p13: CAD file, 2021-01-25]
3d Files/Sensor Mast v22 indv comp/Tilt Mount Body1.stl
21.4 x 34.7 x 14.6

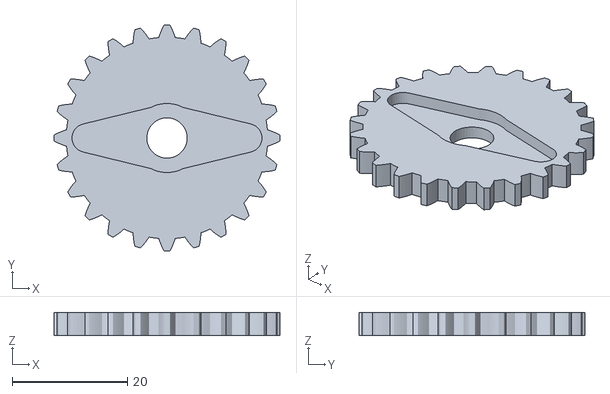
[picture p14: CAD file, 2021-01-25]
3d Files/Sensor Mast v22 indv comp/Drive Gear Pan Optical.stl
39.3 x 39.3 x 4.00

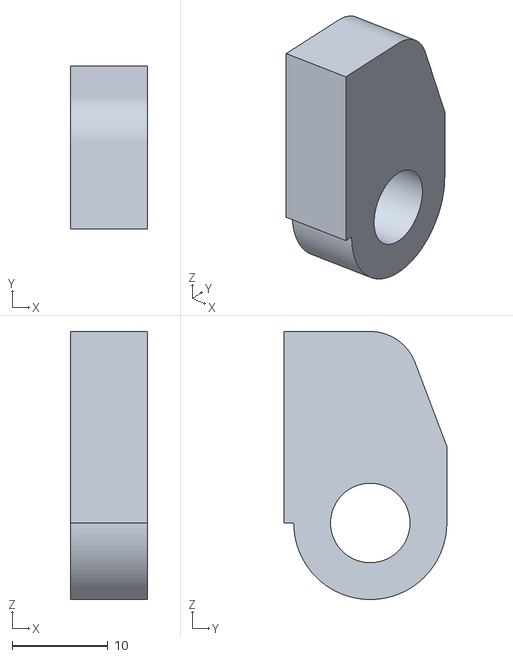
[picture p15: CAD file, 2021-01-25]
3d Files/Sensor Mast v22 indv comp/Hinge Body2.stl
8.00 x 17.0 x 28.0

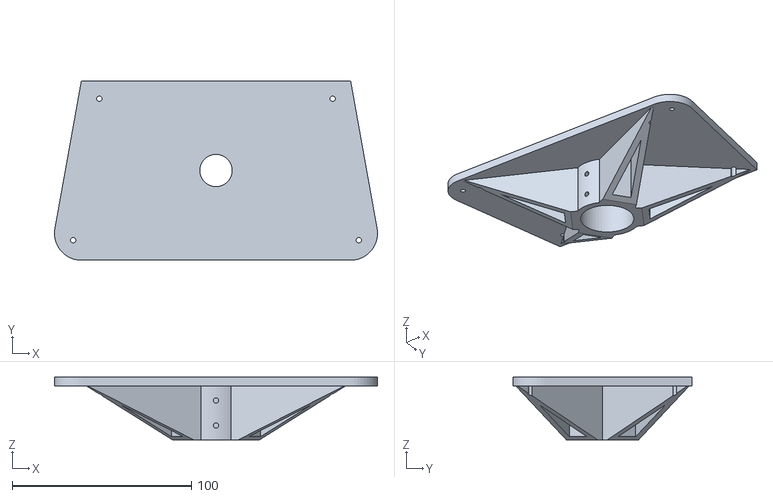
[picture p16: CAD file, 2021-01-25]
3d Files/Sensor Mast v22 indv comp/PVC Pipe Mount.stl
180.0 x 100.0 x 35.0

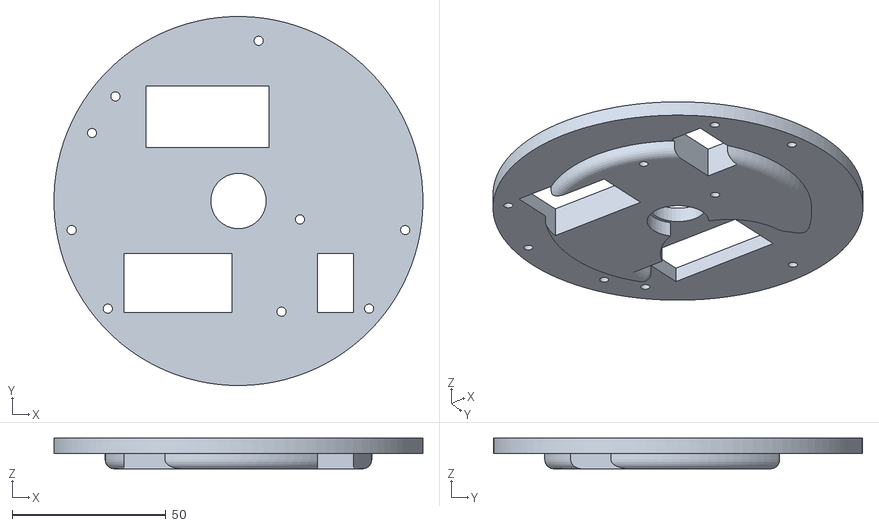
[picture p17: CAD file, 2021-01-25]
3d Files/Sensor Mast v22 indv comp/Optical Base Plate.stl
120.0 x 120.0 x 10.0

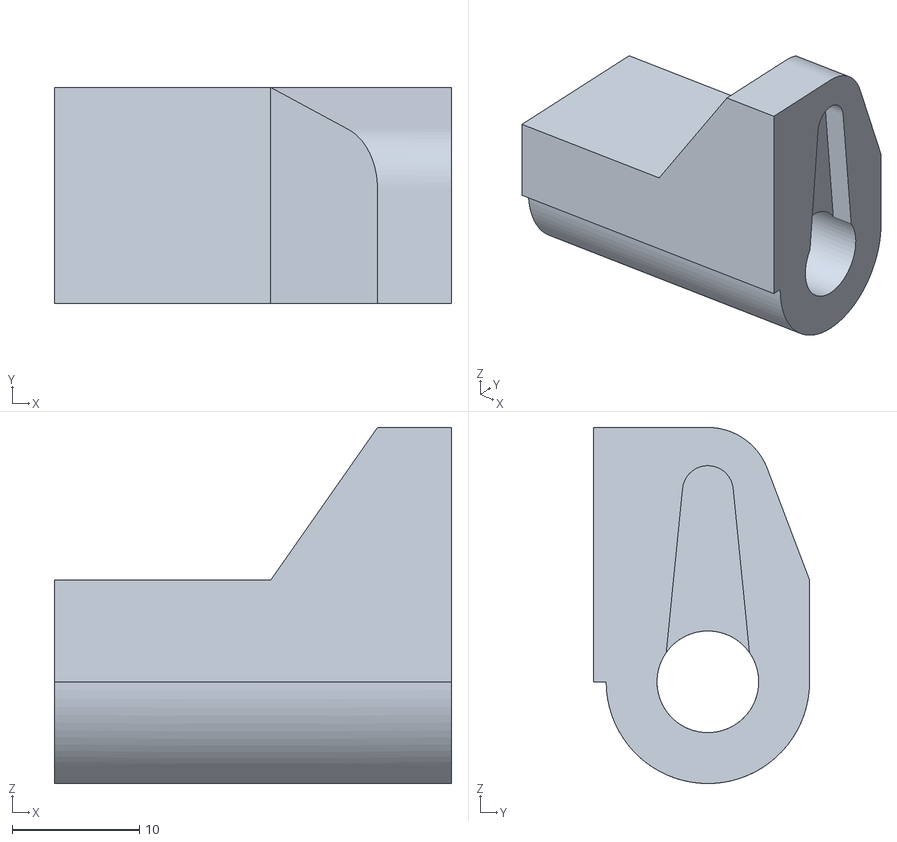
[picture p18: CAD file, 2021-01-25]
3d Files/Sensor Mast v22 indv comp/Hinge Body1.stl
31.2 x 17.0 x 28.0

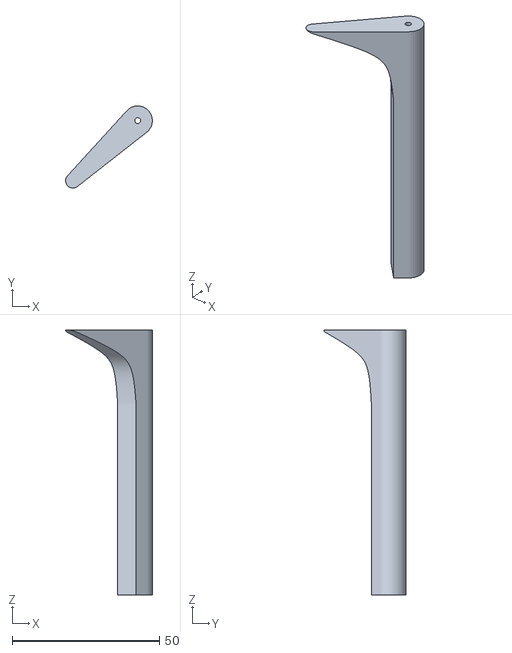
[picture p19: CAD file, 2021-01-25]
3d Files/Sensor Mast v22 indv comp/Pillar.stl
29.5 x 27.9 x 90.0

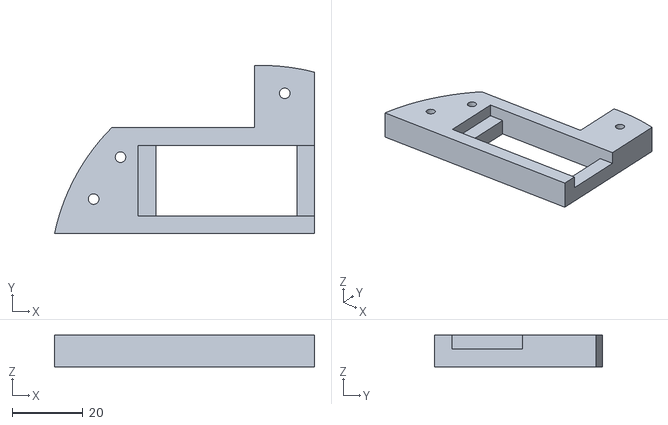
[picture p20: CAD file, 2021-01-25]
3d Files/Sensor Mast v22 indv comp/Pan Servo Optical spacer.stl
73.7 x 47.7 x 9.00

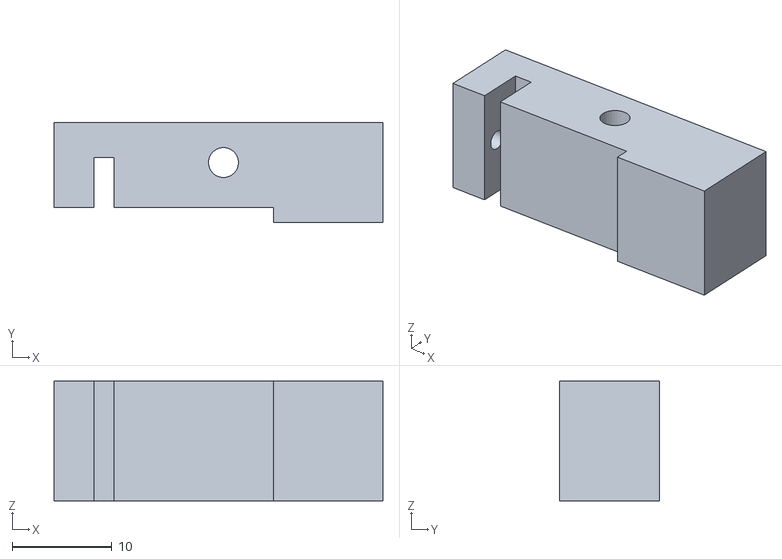
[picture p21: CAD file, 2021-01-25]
3d Files/Sensor Mast v22 indv comp/Tilt Servo Fixer Body1.stl
33.0 x 10.0 x 12.0

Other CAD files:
3d Files/Sensor Mast v22 indv comp/Tilt Mount Body2.stl
3d Files/Sensor Mast v22 indv comp/Backing Shield.stl

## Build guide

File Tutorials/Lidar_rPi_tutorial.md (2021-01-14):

# Tutorial on how to connect and operate lidar on Raspberry Pi.

The YDLidar X4 can be run on either Windows or Linux/Ubuntu. Originally we attempted to run it directly on Debian (based on Raspbian) but encountered errors after attempting to install the ros drivers onto the computer. Consequently, we chose to download a disk image for the RasPi that had Ubuntu 16 and ROS Kinetic installed. This was handy as it saved us the trouble of installing ROS Kinetic manually. This disk image is avaliable at `https://downloads.ubiquityrobotics.com/pi.html`, we used the `2020-11-07-ubiquity-xenial-lxde` version, but if this is not the newest one at the time you access it, the newest one should also work fine. Once the disk image is flashed (we used the Raspberry Pi Imager available on their website to do this), make sure to set it up with the instructions outlined on the Ubiquity Robots link. I will repeate it here in case it is no longer avaliable at time of access.

On startup, the RasPi with the newly installed disk image will host and connect to its own wifi network called `ubiquityrobotXXXX` where the `XXXX` is part of the MAC address. The password for this wifi, by default is `robotseverywhere`. If you have an external monitor it is not neccesary to connect via SSH from a different computer, as everthing can be done directly on the monitor. However it may be beneficial to know how to do this anyway: Once the RasPi is booted up connect your secondary computer to the RasPis wifi network, open terminal and type `ssh ubuntu@10.42.0.1`. This obviously assumes that you have SSH set up on your computer. As default, the password is `ubuntu`, you will have to enter this before you are connected to the RasPi.

When logging in for the first time on a new flashed OS, it's always a good idea to upgrade the software before doing anything else, particularly if your next plans have heavy requirements. This is done with 

```bash
sudo apt-get update
sudo apt-get upgrade
```
##### Updating the keyboard and locale
We are using a German keyboard, so we will see here how to change it from the default US and updating the locale configuration (which control the text language etc of the OS, [see here for more](https://docs.oracle.com/cd/E19455-01/806-0169/6j9hsml2f/index.html)) as they don't seem to be setup correctly on the default image. First the keyboard layout can be set using `sudo dpkg-reconfigure keyboard-configuration`. You can then choose all of the right settings for your specific keyboard.

The next step is to setup the locale, without which you won't be able to use pip with python (for example) and will ruin many other settings you want to do. The commands to do are 

```bash
export LC_ALL=en_US.UTF-8
sudo locale-gen en_US.UTF-8
sudo dpkg-reconfigure locales
```

This should in principle fix all of those. A good test, that will then later become useful for the general project, is to remove the original GPIO pin control (as it's also not working for some reason, by running `sudo apt remove rpi.gpio`. This will completely remove it from the system and then you can reinstall it specifically for the python versions using pip: `pip3 install RPi.GPIO`. This should run without an error and you should then be able to go into the python interpreter and test `import RPi.GPIO`, which should now run without errors, contrarily to earlier.

##### Installing YDLidar-SDK

The RasPi disk image with Ubuntu 16 and ROS should be up and running. Now we have to install the drivers specific to the YDLidar X4. The general procedure is outlined in the YDLidar X4 user manual available at `https://www.ydlidar.com/Public/upload/files/2020-04-13/YDLIDAR-X4-USER%20Manual.pdf` but we will again list the procedure here in case itis not available. 

First you must download/clone the YDLidar-SDK repository from github. 
```bash
git clone https://github.com/YDLIDAR/YDLidar-SDK
```

once this is done you will have to compile and install the YDLidar-SDK on the RasPi with the following.
```bash
$ cd YDLidar-SDK/build
$ cmake ..
$ make
$ sudo make install
```
If this worked, the ROS driver can be installed. However before doing so, you will have download the ROS driver from github, create a catkin workspace for the ydlidar, move the ROS driver into the workspace and then compile the workspace. This can be done with the following commands. it may be beneficial to use the `ls` command to check the move was correctly exectuted before moving onto the compilation
```bash
$ cd ~
$ git clone https://github.com/YDLIDAR/ydlidar_ros_driver
$ mkdir -p ~/ydlidar_ws/src
$ mv /ydlidar_ros_driver /ydlidar_ws/src/
$ cd ~/ydlidar_ws
$ catkin_make
```
now we will add the ydlidar_ws environment to the `~/.bashrc` file:
```bash
$ echo "source ~/ydlidar_ws/devel/setup.bash" >> ~/.bashrc
$ source ~/.bashrc
```
and then we add a device alias to the YDLidar serial port with the command
```bash
$ cd ~/ydlidar_ws/src/ydlidar_ros_driver/startup
$ sudo chmod +x initenv.sh
$ sudo sh initenv.sh
```
one of the final steps is to install RVIZ, a 3d visualisation tool for ROS that will make it easier to view the lidar data
```bash
$ sudo apt-get install python-serial ros-kinetic-serial g++ vim \ros-kinetic-turtlebot-rviz-launchers
```
it may be possible that at this stage the installation fails. in most cases, this can be fixed by updating the source cache and then rerunning the installation, which is the following commands:
```bash
$ sudo apt-get update
$ sudo apt-get upgrade
$ sudo apt-get install python-serial ros-kinetic-serial g++ vim \ros-kinetic-turtlebot-rviz-launchers
```
at this point the RasPi should be ready to run the lidar. Before we get to this, you should check the connections from the lidar. on the X4 there are two micro-usb ports. look carefully on the circuit board, there will be printed usb-data on top of one port and usb-power on the other. The usb-data port should be connected directly to the RasPi. However, we found that the RasPi cannot supply the necessary power, and that if usb-power is connected to the RasPi it will recognise the lidar but return a lidar health error code. You can choose to connect the usb-power to either a normal plug or to your laptop/desktop, both options should have the necessary power for the lidar. Once done:

we can activate the lidar with
```bash
$ roslaunch ydlidar_ros_driver X4.launch
```
the lidar should now be making a big fuss and spinning. to view the data we must run RVIZ and open the correct config file. this is done by opening a new terminal tab and running the command `rviz` which will open the ROS and RVIZ software. Then to load the data click `file >> open config >> ubuntu >> ydlidar_ws >> src >> ydlidar_ros_driver >> launch >> lidar.rviz `. This will load thedata from the lidar and provide real time lidar info. 

to stop the lidar, go back to the terminal tab where you ran the `$ roslaunch ydlidar_ros_driver X4.launch` command and click ctrl-C.

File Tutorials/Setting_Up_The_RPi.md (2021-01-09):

# How to setup the Raspberry Pi (headless connection, remote access, wifi hotspot)

This project relies on the Raspberry Pi to be self relient and disconnected from the grid. This means that we need to set it up to be controlled remotely through ssh or VNC (secreenless or headless in techy terms) and make it host it's own local network for us to connect to. The end goal is to have the RPi host a Flask that we can access by connecting to it's hotspot.

## Flashing the RPi and connecting to it through WLAN/LAN

The fist step consists in actually flashing the RPi SD card with the OS (we used Raspbian as it is really handy). For this you can use any imager software like [Rufus](https://rufus.ie/) or even more practical nowadays, the official RPi Imager that you can find on their [site](https://www.raspberrypi.org/software/). With the latter you don't even need to download the [image of the OS](https://www.raspberrypi.org/software/operating-systems/) on your computer, but both imagers support the old way of actually downloading the Raspbian package onto your computer and flashing it to the SD card (my prefered way, as it also teaches you how to do these things for older or different software, as the concept is the same if you want to install Ubuntu or Debian on our actual machine, which I highly recommend!). The flashing process can take some time, but once it's finished, don't directly put it into the RPi, it need a little more configuration so that you don't require any screens/keyboards for the setting up.

The first step if to open the boot partition of the SD card (you should see two accessible hardrives connected to your computer, go into `boot`). There you simply need to create a new file titled `ssh`, with **NO EXTENTION** (which can be surprisingly complex on Windows; on GNU/Linux and MacOS, simply type `touch ssh` to create it). This simple step will tell the RPi to activate it's ssh connection when booting, which will allow you to take control later on. 

Activating ssh is nice, but it is totally useless if your RPi is not connected to your local network, as you won't be able to access it if it's the case. The configuration for the network is a little more involved but still very basic. In the same `boot` folder, you need to create a file called `wpa_supplicant.conf`. This file will give details to the network manager of the RPi and make it connect to the supplied network information automatically. The file should contain:

```bash
ctrl_interface=DIR=/var/run/wpa_supplicant GROUP=netdev
update_config=1
country=<Insert 2 letter Icountry code - e.g. NL for Netherlands>

network={
 ssid="<Name of your wireless LAN>"
 psk="<Password for your wireless LAN>"
}
```

The fist two lines should not be changed, the third you can simply go on [wikipedia](https://en.wikipedia.org/wiki/ISO_3166-1) to check your country code and the last two entries are simply your wifi name and password. These will not be stored in plain text in case you are wondering.

Now with these two changes done, you can insert the SD card into your Raspberry Pi and turn it on. There are different ways to connect to a RPi for the first time when not yet knowing it's ip address, and probably the easiest is to try `ssh pi@raspberrypi.local`. This might fail if you have more than one RPi with the same name on the network. Once you are in through this method, you can simply type `hostname -I` to find your full ip address, or type `ifconfig` which just gives you more information. The second method consists in using the nmap command `nmap -sn ipAddressOfRouter/24` and find out which of the returned ip's is the RPi. The `ipAddressOfRouter` can be found by finding your own ip and changing the last number to a 1 (so if your local ip is 192.168.0.134, your router ip will be 192.168.0.1). This is a bit more involved because generally computers don't come directly with nmap, and it requires a few extra steps.

Congratulations! Now you should finally be connected to you clead install of Raspbian! the first two steps you should be doing is `sudo apt update` and `sudo apt upgrade` to upgrade all components to latest version available. This might take some time and would benefit from a reboot afterwards (this provides a good test that all your work has worked and you can reconnect even after a reboot). You can also start downloading all the programs/packages that you need for your projects.

## Finalizing the setting up of the RPi (static ip, VNC, I2C, SPI, RPiCam)

Now that you have your RPi up and running there are a few extra things that you might want to do depending on the use you have for your RPi. The first thing you might regret is not having a static ip address, as with time your router assigns a new one to your system and you have to go through figuring out what the ip is once more... It is actually possible to tell the router/modem to allocate you a fixed ip address.

First step to set this up is to check if DHCPCD is active by running `sudo service dhcpcd status` (it should be). If it is not, then you need to run 

```bash
sudo service dhcpcd start
sudo systemctl enable dhcpcd
```

With DHCPCD active, we can now go and make our configuration changes to `sudo nano /etc/dhcpcd.conf`. This means adding these lines:

```bash
interface wlan0
static ip_address=192.168.0.4/24 
static routers=192.168.0.1
static domain_name_servers=192.168.0.1
```

to the opened file. The first line explicitely says what type of interface this connection is (can be`wlan0` for wifi or `eth0` for ethernet conn.). The second is where you set which ip you want to set as static. You only need to change the last number and should be careful to choose a number that your modem will not assign to another device (you can check your DHCP range on your modem settings if you have access). Line 3-4 only explicitely show towards your router, and you have to choose the same ip as yours, but with a 1 a the last place. After this change, just `sudo reboot` and you should be able to reconnect using your new static ip address! This static ip is also very important in case you want to open your server to the rest of the internet and that other people can access it outside of your local network. This is called port-forwarding and can be set up in your modem settings, but will not be covered here.

Lastly, there are many more ways to control or take control of the raspberry pi. These are mostly kept in the same settings area. You can enter it by typing `sudo raspi-config`. This opens a GUI with many choices. To change the authorizations for remote interfaces etc, go into the subcategory "Interface Options" and there you can activate the RPi camera, the SPI and I2C connections and the VNC tunnelling (I don;t use much else from there, but keep in mind for the other interfaces you might one day use!

For the moment this is all, I hope you enjoyed and learned something! :)

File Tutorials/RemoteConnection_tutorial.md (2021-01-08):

# Remotely controlling a Raspberry Pi

The most direct way to connect to any remote server, be it a RPi or just another server for your work or research, is through SSH (Secure SHell). This method creates a secure tunnel between you and the remote address you are trying to connect to. Once you have ssh installed (generally comes pre-installed on GNU/Linux and MacOS; needs to be installed through PuTTY or similar for windows) you can just open the terminal and create the connection.

The command to connect is simply `ssh user@ip_address -p port_nb`. This should make a connection and you can enter the password. So for example if your remote server has the ip address 127.0.0.1:5000 with you user named Alice, you should type in `ssh Alice@127.0.0.1 -p 5000`. 

#### Controlling the remote system

Now that you are connected, you need to be able to do things with the connection. Here I assume you have a Linux/Debian based system (like Ubuntu or Raspbian). The most important commands are:

- `cd directoryName` for changing directory. You can have multiple directories separated by `/` , moving back one directory you'll use `..` and the directory you are in is represented by a single `.`
- `ls` to list the items in the current directory
- `pwd` to print the current (called working) directory
- `cp dirFrom/filename dirTo` to copy a file to a directory. If you want to copy a file to the current dir, you have to put a dot instead of the `dirTo`. If you want to copy a directory that has files insde and maybe subdirectories, you have to use `cp -r` that stands for recursive copying.
- `mv dirFrom/filename dirTo` to move a file. This can also be used to rename files, by moving them and having the new name as final destination.
- `rm filename` to remove a file. You can also remove a directory recursively by adding `-r`
- `nano filename` to modify the text content of a file. If the file doesn't exist it will create it. There are other editors available like vim or emacs, but I use nano personally.

Of course dempending on the software you have you will have many more commands that you have to use, like `python3 filename.py` to run a python script etc... All these commands have alot of different options, too many to summarize here, so if you need more out of a command you  can always call `command --help` and this will list the different possibilities. Equally useful is testing if some command exists, which I generally do by checking for the version with `command --version` as it doesn't do anything else than return the version number.

Depending on the location of the files you want to modify, you might not have enough priviledge as a simple user. This can be modified with the `chmod` command, but I will let you explore all this by yourself. This command comes with a catch however, as it relies on you having enough priviledge to make that change, which you don't have. This means that you need to define yourself as the superuser of the system, by adding `sudo` in front of the command ou want to take. This gived you the right do do basically anything on the computer, granting you with great power, but just as much responsability, as this will allow you to, for example, delete files that are necessary for the normal function of the system you are on.

#### Installing software

This `sudo` command is also necessary for you to install new software on your machine. The simplest way to download anything is using the packet managet apt, with `sudo apt install packageName`. There are more convoluted ways to install software that is not available on apt, by downloading a compressed .deb file or building the package from source, but this will not be covered here. Doing this also ensures that the software is the latest/specific version that you want, as apt is only updated infrequently. The deletion of software is done with `sudo apt remove packageName`. 

#### Transfering files from remote desktop

The process to send files from the remote system to the local one is the same as the simple `cp` but is done through ssh. The command is `scp -p port user@ipaddress:remoteDirectory/filename localDirectory`. With this you can also send files by just inverting the recieving and sender ends.

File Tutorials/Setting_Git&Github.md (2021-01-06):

# How to use git for version control

Github is a website for version control, code sharing and code storing. This is the perfect interface for a group project as well as a more massive personal project as it allows you to come back to previous versions of the code as well as keep track of what other people have to say about your contibutions.

This text will quickly remind what are the important features of github and the git commands that go with it.

### Initial downloads and settings

Using github only through the web interface is very inefficiant and clumsy. It is much better to have a version of the repository on your own computer and make all the changes directly there. The first step is of course to [downoald Git](https://git-scm.com/downloads). If you are using mac or linux you might have it pre-installed, so check in the terminal by entering `git --version`. If you have it it should just outpus something like `git version 2.25.1`. Of course for the next steps you will need a Github account. 

Hopefully the installation has gone nicely and you have a fresh version on your computer. It is now time to link your Github account to your installation. For this, just follow the information on this [page](https://docs.github.com/en/free-pro-team@latest/github/authenticating-to-github/about-ssh). It will teach you how to create a secure connection between your computer to the Github mainframe. If on windows, you might also need to download ssh through [PuTTY](https://www.putty.org/).

We now have all the tools to start participating to the project! The first step now, is to clone the repo. This is done on the main page and clicking the **Code** button and copying the SSH link. In your terminal, you go to the folder you want the download to be done using the change directory `cd` command, e.g. `cd firstDir/secondDir/` and then using the cloning git command `git clone copiedGithubLink` 

From there on you have your personal version of the repository (!! be sure that you are a collaborator to the project, otherwise you won't be able to make modifications !!). 

### Steps to manage personal branches and code

The master branch is reserved to mature and ready code, this is not the place you want to upload your unfinished or partially working code. This means you will create your own branch of the project to work on which is separate and as such doesn't impact the master branch.

##### Creating your branch

The command is `git checkout -b BranchName`. The same command without the `-b` is used to switch from branch to branch in the repository. The command puts you directly in the new branch and you can start working on your code. An extra step is to just verify the branch you are on with `git status`. This command gived you general information about the status of your branch and your branch name.

Once you are satisfied with your work and think is is the time to create a lasting step in the progress, it is time to commit your work to your branch.

##### Uploading your code to Github 

While working on your files locally on the computer, nothing is sent to github to be stored, meaning that you have to do this manually everytime you think your code is worthy of upload (generally everytime you manage to complete a specific task in your program). The steps can be summarized as: `add`, `commit` and `push`.

The first step is to decide which files are ready to be sent to github (commited to the site in the git language). By typing `git status`, you will see all of the modified files you have been working on. They appear in red because they have not been selected to be commited to the Github repository. To change that, you will have to use the `add` command. Choosing a specific file to commit is done with `git add FileName`. Generally there are many files and as said above, you are probably happy with a big part of your code at this point, so you can also add all the files in one go using `git add -A`.

Once you are satisfied with the files to commit, you can simply create the commit by entering `git commit -m "Commit message"`. The message is important, as the commit will not be accepted without one. If you forget the `-m "message"`, you will be put into Vim, which is a command line text editor that can be intimidating to the non initiated. If that happens, just type `:qa` and enter and this should leave the prompt and cancel the commit. After that you just have to redo the commit command.

Now that you have created the commit, the last step is to just `push` the changes to github with the command `git push origin YourBranchName`. This will upload your changes to the site. The `origin` means that the commit comes from your local computer and `YourBranchName` is the name of the branch you are working on. It is good practice to always have those two words to make sure that you are pushing your files to the right place.

You can now go and check on the github website that all of your new files have correctly been uploaded :)

##### Pulling from Github

It is sometimes possible that changes chave been made to your branch by someone else than yoursel, meaning that your local version is not synchronized with the online version of the reepository. To fix that, before you can push your commit you will have to pull down the extra code that you don't have. This is done simply with the `git pull` command. If you wannt to synchromize your branch with the master branch then you can call `git pull origin master`, but this is not something that I have ever used in practice.

## Summary

If you follow the steps above you will theoretically always succeed in uploading you files! This is a quick summary of all the steps necessary, assuming you are already on your personnal branch:

1. `git add -A` 
2. `git commit -m "Short explanation of the changes"`
3. `git push origin YourBranchName`
4. Possibly `git pull` in case your branch has been modified

If you want to check what files are included in the commit or which branch you are in, type `git status`. If you want to change to another branch use `git checkout BranchName`, including `master`.

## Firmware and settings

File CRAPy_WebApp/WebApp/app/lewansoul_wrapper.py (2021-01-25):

"""
MIT License

Copyright (c) 2018 Roger Cheng

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
import configuration

def bytetohex(bytearray):
  """
  Returns hexadecimal string representation of byte array
  Copied from StackOverflow
  https://stackoverflow.com/questions/19210414/byte-array-to-hex-string
  """
  return ''.join('{:02x}'.format(x) for x in bytearray)

class lewansoul_wrapper:
  """
  Class that implements the rover motor control methods for serial bus
  servo by LewanSoul. Specifically their model LX-16A.
  """
  def __init__(self):
    self.sp = None

  def check_sp(self):
    """ Raises error if we haven't opened serial port yet. """
    if self.sp == None:
      raise ValueError("LewanSoul serial communication is not available.")

  def connect(self):
    """
    Read serial port connection parameters from JSON configuration file
    and open the port.
    """

    # Read parameter file
    config = configuration.configuration("lewansoul")
    connectparams = config.load()['connect']

    # Open serial port with parameters
    s = serial.Serial()
    s.baudrate = connectparams['baudrate']
    s.port = connectparams['port']
    s.timeout = connectparams['timeout']
    s.open()

    if s.is_open:
      self.sp = s

  def close(self):
    """
    Closes down the serial port
    """
    if self.sp.is_open:
      self.sp.close()
      self.sp = None

  def send(self, servo_id, command, data=None):
    """
    Send a command to a LewanSoul servo, taking care of the header and
    checksum calculation for a command packet.
    """
    self.check_sp()
    packet = [0x55, 0x55]

    if servo_id < 0 or servo_id > 0xfe:
      raise ValueError("Servo ID {} is out of valid range".format(servo_id))
    packet.append(servo_id)

    length = 3
    if data:
      length = length + len(data)
    #TODO: check maximum length
    packet.append(length)

    #TODO: Check for valid command
    packet.append(command)

    if data:
      for d in data:
        packet.append(d)

    checksum = servo_id + length + command
    if data:
      for d in data:
        checksum = checksum + d
    checksum = (~checksum) & 0xff
    packet.append(checksum)

    packet_bytes = bytearray(packet)
    # print("Sending command byte stream of {}".format(bytetohex(packet_bytes)))
    self.sp.write(packet_bytes)

  def read_raw(self, length=100):
    """
    Reads a stream of bytes from serial device and returns it without any
    attempts at parsing or validation
    """
    self.check_sp()
    return bytearray(self.sp.read(length))

  def read_parsed(self, length=100, expectedid=None, expectedcmd=None, expectedparams=None):
    """
    Reads up to 'length' bytes and parse it according to pack format spec
    from "LewanSoul Bus servo Communication Protocol" PDF:

    0     1     2     3     4     [ ... ]
    0x55  0x55  ID    Len   Cmd   Param1... ParamN  Checksum

    Length of data is all bytes after ID, including length byte.
    Packet with no parameters has length of 3 bytes, plus header+ID = 6 bytes total.
    Checksum = (~(ID+Length+Cmd+Param1+...+ParamN)) & 0xFF

    - -

    Optional parameters:
      expectedid = if provided, will check message ID against expected ID.
      expectedcmd = if provided, will check message command against expected command.
      expectedparams = if provided, will check the number of bytes in parameter matches expected.

      If a mismatch is found, a ValueError is raised.
    """
    self.check_sp()
    r = bytearray(self.sp.read(length))

    # Check response length
    if len(r) < 6:
      raise ValueError("Need at least 6 bytes for a valid packet, received {}".format(len(r)))

    # Check header
    if r[0] != 0x55 or r[1] != 0x55:
      raise ValueError("Response header is {:02x} {:02x}, expected 0x55 0x55".format(r[0], r[1]))

    # Verify length
    rlen = r[3]
    if rlen+3 != len(r):
      raise ValueError("Packet claims to have {} bytes of data + 3 bytes of header, but we retrieved {} bytes.".format(rlen, len(r)))

    # Verify checksum
    checksum = 0
    for b in r[2:-1]:
      checksum = checksum + b
    checksum = (~checksum) & 0xFF

    if checksum != r[-1]:
      raise ValueError("Packet checksum {} does not match calculated checksum {}".format(r[-1], checksum))

    # If an expected ID is given, compare against ID in the message.
    rid = r[2]
    if expectedid != None and expectedid != rid:
      raise ValueError("Response stamped with ID {}, expected {}".format(rid, expectedid))

    # If an expected command is given, compare against command in the message.
    rcmd = r[4]
    if expectedcmd != None and expectedcmd != rcmd:
      raise ValueError("Response command {}, expected {}".format(rcmd, expectedcmd))

    # Examine parameters, if any.
    if rlen > 3:
      rparams = bytearray(r[5:-1])
      if expectedparams != None and expectedparams != len(rparams):
        raise ValueError("Received {} bytes of parameters, expected {}".format(len(rparams),expectedparams))
    else:
      rparams = None
      if expectedparams != None and expectedparams != 0:
        raise ValueError("Received {} bytes of parameters, expected none".format(len(rparams)))

    # Return results in a tuple
    return (rid, rcmd, rparams)

  def version(self, id):
    """ Identifier string for this motor controller """
    return "LewanSoul"

  @staticmethod
  def check_id(id):
    """ Verifies servo ID is within range and inverted status is boolean"""
    if not isinstance(id, (tuple,list)):
      raise ValueError("LewanSoul identifier must be a tuple")

    if not isinstance(id[0], int):
      raise ValueError("LewanSoul servo address must be an integer")

    if id[0] < 0 or id[0] > 253:
      raise ValueError("LewanSoul servo address {} outside of valid range 0-253".format(id[0]))

    if not isinstance(id[1], int):
      raise ValueError("LewanSoul servo center position must be an integer")

    if not isinstance(id[2], bool):
      raise ValueError("Inverted status must be a boolean")

    return tuple(id)

  def power_percent(self, id, percentage):
    """ Runs servo in motor mode at specified +/- percentage """
    sid, center, inverted = self.check_id(id)
    self.check_sp()

    pct = int(percentage)
    if abs(pct) > 100:
      raise ValueError("Motor power percentage {0} outside valid range from 0 to 100.".format(pct))

    # LewanSoul API wants power expressed between -1000 and 1000, so multiply by 10.
    power = percentage*10

    if inverted:
      power = power * -1

    self.send(sid, 29, bytearray(pack('hh',1,int(power))))

  def set_max_current(self, id, current):
    """ LewanSoul does not support overpower protection. """
    sid, center, inverted = self.check_id(id)
    self.check_sp()
    # Does nothing

  def init_velocity(self, id):
    """ Sets LewanSoul into motor mode and speed zero """
    sid, center, inverted = self.check_id(id)
    self.check_sp()

    self.send(sid, 29, bytearray(pack('hh',1,0)))

  def velocity(self,id,pct_velocity):
    """
    Runs the specified servo in motor mode at specified velocity
    In case of LewanSoul servos, it is the same as power_percent.
    """
    self.power_percent(id,pct_velocity)

  def init_angle(self, id):
    """
    Sets the LewanSoul into servo mode and move to center over 2 seconds
    """
    sid, center, inverted = self.check_id(id)
    self.check_sp()

    self.send(sid, 29, (0,0,0,0)) # Servo mode
    self.send(sid, 1, bytearray(pack('hh', center, 2000)))

  def maxangle(self, id):
    sid, center, inverted = self.check_id(id)
    self.check_sp()
    return 120

  def angle(self, id, angle):
    sid, center, inverted = self.check_id(id)
    self.check_sp()

    if abs(angle) > 95:
      raise ValueError("Steering angle {} exceeded expected maximum of 90".format(angle))

    delta = angle * (500.0/120.0) # 500 count/ 120 degrees = counts per degree.

    if inverted:
      delta = delta * -1

    self.send(sid, 29, (0,0,0,0)) # Servo mode
    self.send(sid, 1, bytearray(pack('hh', int(center+delta), 200)))

  def steer_setzero(self, id):
    sid, center, inverted = self.check_id(id)
    self.check_sp()
    # TODO: Support live adjustment

  def input_voltage(self, id):
    """
    Query LewanSoul servo's internal voltage monitor
    """
    sid, center, inverted = self.check_id(id)
    self.check_sp()

    self.send(sid, 27)
    (sid, cmd, params) = self.read_parsed(length=8, expectedcmd=27, expectedparams=2)
    millivolts = unpack('h', params)[0]

    return millivolts/1000.0

if __name__ == "__main__":
  """
  Command line interface to work with LewanSoul serial bus servos.
  Implements a subset of the servo's functionality
  * Move to position over time. (Servo mode)
  * Spin at a specified speed. (Motor mode)
  * Broadcast query for servo ID
  * Rename servo to another ID
  * Unload and power down motors
  """
  import argparse

  parser = argparse.ArgumentParser(description="LewanSoul Serial Servo Command Line Utility")

  parser.add_argument("-id", "--id", help="Servo identifier integer 0-253. 254 is broadcast ID.", type=int, default=1)
  parser.add_argument("-t", "--time", help="Time duration for action", type=int, default=0)
  group = parser.add_mutually_exclusive_group()
  group.add_argument("-m", "--move", help="Move servo to specified position 0-1000", type=int)
  group.add_argument("-q", "--queryid", help="Query for servo ID", action="store_true")
  group.add_argument("-r", "--rename", help="Rename servo identifier", type=int)
  group.add_argument("-s", "--spin", help="Spin the motor at a specified speed from -1000 to 1000", type=int)
  group.add_argument("-u", "--unload", help="Power down servo motor", action="store_true")
  group.add_argument("-v", "--voltage", help="Read current input voltage", action="store_true")
  args = parser.parse_args()

  c = lewansoul_wrapper()
  c.connect()

  if args.move != None: # Explicit check against None because zero is a valid value
    if args.move < 0 or args.move > 1000:
      print("Servo move destination {} is outside valid range of 0 to 1000 (1000 = 240 degrees)".format(args.move))
    elif args.time < 0 or args.time > 30000:
      print("Servo move time duration {} is outside valid range of 0 to 30000 milliseconds".format(args.time))
    else:
      print("Moving servo {} to position {}".format(args.id, args.move))
      c.send(args.id, 29, (0,0,0,0)) # Turn on servo mode (in case it was previously in motor mode)
      c.send(args.id, 1, bytearray(pack('hh', args.move, args.time)))
  elif args.queryid:
    print("Broadcasting servo ID query")
    c.send(0xfe, 14) # Broadcast and ask to report ID
    (sid, cmd, params) = c.read_parsed(length=7, expectedcmd=14, expectedparams=1)
    if sid != params[0]:
      raise ValueError("ID response stamped with {} but payload says {}".format(sid, params[0]))
    print("Servo ID {} responded to query".format(sid))
  elif args.rename:
    print("Checking the specified servo ID {} is on the serial network.".format(args.id))
    c.send(args.id, 14) # Ask for current servo ID
    (sid, cmd, params) = c.read_parsed(length=7, expectedcmd=14, expectedparams=1)
    if sid != args.id or params[0] != args.id:
      print("Unexpected answer from servo {} when verifying servo {} is on the network.".format(sid, args.id))
    else:
      print("Checking the specified destination servo ID {} is not already taken.".format(args.rename))
      c.send(args.rename, 14)
      expectempty=c.read_raw()
      if len(expectempty) > 0:
        raise ValueError("Someone answers to servo ID {} on the network, rename aborted.".format(args.rename))
      else:
        print("Renaming servo ID {} to {}".format(args.id, args.rename))
        c.send(args.id, 13, (args.rename,))
        print("Verifying the servo now answers to new ID")
        c.send(args.rename, 14)
        (sid, cmd, params) = c.read_parsed(length=7, expectedcmd=14, expectedparams=1)
        if sid != args.rename or sid != params[0]:
          print("Querying for response from ID {} failed, we got answer from ID {}/{} instead.".format(args.rename, sid, params[0]))
        else:
          print("Servo successfully renamed to ID {}".format(args.rename))
  elif args.spin != None: # Zero is a valid parameter.
    if args.spin < -1000 or args.spin > 1000:
      print("Servo spin speed {} is outside valid range of -1000 to 1000".format(args.spin))
    else:
      print("Spinning motor of servo {} at rate of {}".format(args.id, args.spin))
      c.send(args.id, 29, bytearray(pack('hh', 1, args.spin)))
  elif args.unload:
    c.send(args.id, 31, (0,))
  elif args.voltage:
    c.send(args.id, 27)
    (sid, cmd, params) = c.read_parsed(length=8, expectedcmd=27, expectedparams=2)
    voltage = unpack('h', params)[0]
    print("Servo {} reports input voltage of {}".format(sid, voltage/1000.0))
  else:
    # None of the actions were specified? Show help screen.
    parser.print_help()

  c.close()

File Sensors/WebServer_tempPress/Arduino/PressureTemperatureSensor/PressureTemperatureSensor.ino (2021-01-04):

#include <Wire.h>
#include <SPI.h>
#include <Adafruit_BMP280.h>

//all the pins can be chosen as wishes
#define BMP_SCK  (13) //SCK
#define BMP_MISO (10) //SDO
#define BMP_MOSI (12) //SDI
#define BMP_CS   (11) //CS

//Adafruit_BMP280 bmp(BMP_CS); //HARDWARE SPI
Adafruit_BMP280 bmp(BMP_CS, BMP_MOSI, BMP_MISO,  BMP_SCK);

void setup() {
  Serial.begin(9600);

  if (!bmp.begin()) {
    Serial.println(F("Could not find a valid BMP280 sensor, check wiring!"));
    while (1);
  }

  /* Default settings from datasheet. */
  bmp.setSampling(Adafruit_BMP280::MODE_NORMAL,     /* Operating Mode. */
                  Adafruit_BMP280::SAMPLING_X2,     /* Temp. oversampling */
                  Adafruit_BMP280::SAMPLING_X16,    /* Pressure oversampling */
                  Adafruit_BMP280::FILTER_X16,      /* Filtering. */
                  Adafruit_BMP280::STANDBY_MS_500); /* Standby time. */
}

void loop() {
    Serial.print(String(bmp.readTemperature()) + "," + String(bmp.readPressure()) + "," + String(bmp.readAltitude(1023)) + "\n");
    delay(1000);
}

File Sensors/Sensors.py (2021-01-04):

#Project Brover @2020
#Simon Stoll
from Sonic_sensor import *
import RPi.GPIO as GPIO
import time
import sqlite3
conn = sqlite3.connect('Sensordata.db')
c = conn.cursor()
GPIO.setmode(GPIO.BCM)

#Front Sensor Pin location
TRIG1 = 14
ECHO1 = 15

#Back Sensor Pin location
TRIG2 = 18
ECHO2 = 23

#Call other class to run the sensors
setup(TRIG1,ECHO1)
pulse_duration = trigger(TRIG1,ECHO1)
dist1 = distance(pulse_duration)

setup(TRIG2,ECHO2)
pulse_dur = trigger(TRIG2,ECHO2)
dist2 = distance(pulse_dur)

theTime = time.asctime()
#Add server for database
c.execute("INSERT INTO Sonic VALUES (?,?,?,?);" ,(NULL,dist1,dist2,theTime))
conn.commit()
c.close()

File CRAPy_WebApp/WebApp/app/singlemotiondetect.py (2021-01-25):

import numpy as np
import imutils
import cv2

class SingleMotionDetect:
    def __init__(self, accumWeight=0.5):
        self.accumWeight = accumWeight
        self.bg = None

    def update(self, image):
        if self.bg is None:
            self.bg = image.copy().astype("float")
            return
        # update the background model by accumulating the weighted
        # average
        cv2.accumulateWeighted(image, self.bg, self.accumWeight)

    def detect(self, image, tVal=25):
        # compute the absolute difference between the background model
        # and the image passed in, then threshold the delta image
        delta = cv2.absdiff(self.bg.astype("uint8"), image)
        thresh = cv2.threshold(delta, tVal, 255, cv2.THRESH_BINARY)[1]
        # perform a series of erosions and dilations to remove small
        # blobs
        thresh = cv2.erode(thresh, None, iterations=2)
        thresh = cv2.dilate(thresh, None, iterations=2)

        # find contours in the thresholded image and initialize the
        # minimum and maximum bounding box regions for motion
        cnts = cv2.findContours(thresh.copy(), cv2.RETR_EXTERNAL,
        	cv2.CHAIN_APPROX_SIMPLE)
        cnts = imutils.grab_contours(cnts)
        (minX, minY) = (np.inf, np.inf)
        (maxX, maxY) = (-np.inf, -np.inf)

# if no contours were found, return None
        if len(cnts) == 0:
            return None
        # otherwise, loop over the contours
        for c in cnts:
            # compute the bounding box of the contour and use it to
            # update the minimum and maximum bounding box regions
            (x, y, w, h) = cv2.boundingRect(c)
            (minX, minY) = (min(minX, x), min(minY, y))
            (maxX, maxY) = (max(maxX, x + w), max(maxY, y + h))
        # otherwise, return a tuple of the thresholded image along
        # with bounding box
        return (thresh, (minX, minY, maxX, maxY))

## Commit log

2020-06-10 Added Laser turret
2020-06-24 Added calibration()
2020-06-26 Sensor python files
2020-06-26 Sensors update
2021-01-06 Lidar first update
2021-01-06 v4 of lidar environmet code
2021-01-06 update with movement fix and geometric boundary fix, also sligh graphical change
    [Lidar_v5.pde]
2021-01-10 assembled stl file
    [Sensor Mast v22.stl]
2021-01-10 individual component files
    [Backing Shield.stl, Drive Gear Pan Optical.stl, Hinge Body1.stl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]
2021-01-20 servo connection
2021-01-21 Working prototype of the web application - needs integration
2021-01-24 Basis for the lidar stream
2021-01-24 Added working script of LiDAR websockets
2021-01-24 Webserver functionality for robo arm
